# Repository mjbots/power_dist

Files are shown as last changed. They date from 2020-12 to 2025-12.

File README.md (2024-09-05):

# mjbots power_dist and mjpower-ss #

This repository contains hardware and firmware for the mjbots
power_dist and mjpower-ss boards.  Both provide pre-charge,
over-current limiting and connector fanout.  The power_dist
additionally provides energy monitoring and a soft-switch
functionality.

# Specifications #

| Name | power_dist r4.5b | mjpower-ss r2 |
| --- |---|---|
| Voltage Input | 10-44V | 10-54V |
| Current (continous/peak) | 45A/90A | 45/90A |
| Output | 6x XT30 | 6x XT30 |
| Max load capacitance | 4000uF | 4000uF |
| Quiescent current | 300uA | 200uA |
| Dimensions | 80x50mm | 70x50mm |
| Mass | 36g | 34g |
| External switch | X | X |
| Soft switch | X | |
| Onboard switch | | X |
| CAN communication | X | |

# Documentation #

* [Reference](docs/reference.md)

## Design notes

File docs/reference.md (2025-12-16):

mjbots power_dist and mjpower-ss reference

# A. Operation #

The `power_dist` and mjpower-ss boards provides pre-charging, an
external power switch, and a power connector fanout for use in robotic
applications.  Additionally, the `power_dist` provides energy
monitoring and over-current protection, and a soft switch capability.

The input can be directly connected to a battery or power supply.  The
output can be connected to high capacitance loads.

For the `power_dist`, a CAN-FD port allows host software to monitor
the state of the switch, input voltage, power, and energy, and request
that shutdown be delayed to accomplish a "soft power down".  This
documentation refers to the most recent (r4.5b) version of the
`power_dist`.  r4.3 versions are largely compatible with this as well.

# A. Register command set (power_dist only) #

The `power_dist` uses the same register framing and CAN-FD as the mjbots moteus controllers, with alternate definitions for the registers.  [moteus reference](https://github.com/mjbots/moteus/blob/main/docs/reference.md#a-register-command-set)

The default ID for the power_dist is '32', (which notably differs from
the default id of 1 for the moteus controller).

## A.2 ##

The following additional mappings are provided.

### A.2.a Energy (measured in W*hr) ###

- int8 => 1 LSB => 1 W*hr
- int16 => 1 LSB => 0.01 W*hr
- int32 => 1 LSB => 0.000001 W*hr

## Registers ##

### 0x000 - State ###

Mode: Read only

The current operational state of the power_dist.

- 0 => power off
- 1 => precharging
- 2 => power on
- 3 => fault

### 0x001 - Fault Code ###

Mode: Read only

A 7 bit fault code.

### 0x002 - Switch status ###

Mode: Read only

Zero if the switch is current turned off, non-zero otherwise.

### 0x003 - Lock time ###

Mode: Read/write

Power will be maintained for this long after the switch has been
turned off.  The maximum value is 3276.7s, all register scalings
report in units of 100ms (thus int8 will not be able to command or
monitor the full possible scale).

### 0x004 - Boot time ###

Mode: Read

Time since the processor was powered.

### 0x010 - Output Voltage ###

Mode: Read only

The current output voltage

### 0x011 - Output Current ###

Mode: Read only

The current output current.

### 0x012 - Temperature ###

Mode: Read only

The current output FET temperature.

### 0x013 - Energy ###

Mode: Read only

Total energy provided to the downstream port since power was enabled.

# B. diagnostic command set (power_dist only) #

All `tel` and `conf` class commands from [moteus
reference](https://github.com/mjbots/moteus/blob/main/docs/reference.md#b-diagnostic-command-set)
are supported.  In addition, the following diagnostic mode commands
are available.

## `p lock` ##

Request that the lock time be set.

```
p lock <time_in_100ms>
```

## `p force off` ##

Request that the output be turned off.  The device will not enter
sleep, which differs from the behavior when power off is achieved
through the physical switch.  While the "force" mode is activated, the
switch has no effect.

## `p force on` ##

Request that the output be turned on.  This enables "force" mode,
which disables the physical switch.

## `p force disable` ##

Remove "force" mode, which will re-enable the physical switch.

# C. Mechanical / Electrical #

## Mechanical ##

`power_dist`: 4x M2.5 mounting holes are provided in a 74mm x 44mm rectangular pattern.

`mjpower-ss`: 4x M2.5 mounting holes are provided in a 64mm x 44mm rectangular pattern.

## Pinout ##

### XT-90 Input ###

The XT-90 connector has a `-` and a `+` imprint on the housing.

### XT-30 Output ###

The XT-30 connectors have a `-` and a `+` imprint on the housing.

### JST PH-4 Switch ###

A small white dot is present on the silk screen near pin 1.

 - 1 - LED+ - LED positive
 - 2 - LED- - LED ground
 - 3 - SWG - Switch ground
 - 4 - SWP - Switch positive

### Onboard Switch (mjpower-ss only) ###

The onboard switch is connected in parallel to the external switch.
If either the onboard switch is set to the ON position, or the
external switch pins are tied together, the board will pre-charge and
provide power to the output when the input voltage reaches a small
threshold below the minimum input voltage.

### JST PH-3 CAN (power_dist only) ###

Looking at the pins of the connector with the mjbots logo right side
up, the pins are numbered from the bottom to the top.

 - 1 - CAN_H
 - 2 - CAN_L
 - 3 - GND

NOTE 1: CAN connections should be terminated by a 120 ohm resistor at
both ends of a bus.  Some mjbots products have built in termination
resistors, such as the pi3hat.  The fdcanusb has a software
configurable termination resistor that is by default on.  The
power_dist board has no termination resistors.  For very short runs,
the system will work terminated only on one side.  However, when runs
become longer than 0.5m, you will likely need to terminate both ends.
This can be done by crimping a 120 ohm resistor into a JST PH3
connector and connecting it to the open data connector.

NOTE 2: Ground may not be necessary, only one path through ground in a
system should exist to avoid ground loops.  In a typical robot
application with a common ground, that role is filled by the power
ground.  However, in desktop applications, it may be appropriate to
connect the CAN ground if the device power supply is otherwise
isolated.

### JST ZH-6 SWD (power_dist only) ###

Looking at the pins of the connector with the mjbots logo right side
up the pins are numbered 1 to 6 from top to bottom.

 - 1 - NC
 - 2 - NRST
 - 3 - SWDIO
 - 4 - GND
 - 5 - SWCLK
 - 6 - 3.3V

# D. Maintenance (power_dist only) #

## Building firmware ##

Building is supported on Ubuntu 20.04 with the following command:

```
tools/bazel test //:target
```

## Flashing firmware ##

A firmware image (.elf file), can be flashed from a linux PC using the
6-pin SWD debug connector.

One time:

```
sudo apt install binutils-arm-none-eabi
```

Ensure that power is applied, the switch is turned on, and no loads
are connected, then:

```
fw/flash.py optional/path/to/file.elf
```

## openocd ##

As with moteus, openocd 0.11.0 or newer is required, see:

https://github.com/mjbots/moteus/blob/main/docs/reference.md#openocd

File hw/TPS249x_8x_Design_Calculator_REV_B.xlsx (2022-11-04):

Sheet: Instructions
 | © 2016
TPS249x/8x Design Tool- Rev. B
Typical design procedure
Typical applications require multiple passes through the design tool using MOSFET factors such as transient
thermal response and safe operating area curves. Refer to the following application reports for more detail.
Robust Hot Swap Design (http://www.ti.com/lit/pdf/slva673)
The basic design process follows:
1. Enter operating conditions.
2. Select current limit parameters.
3. Enter MOSTFET SOA characteristics & power limit.
4. Select start up conditions (load and/or soft start). Check whether FET is operating with reasonable margin, within the SOA curve.
If not, try changing start-up conditions (soft start values, timer values), add more FETs in parallel, or switch to FET with better SOA.
5. Enter desired UVLO and OVLO values to get recommended resistor values.
6. Done
Notes
1. This worksheet is designed for use with Microsoft Excel 5.0 or later. Its use is intended to assist power supply designers in their
routine, day-to-day calculations.
2. All worksheets have light green inputs cells, white calculated cells, yellow warning cells and red high-risk cells.
3. Formulas and device constants used in the spreadsheet are locked to prohibit them from accidentally being overwritten or deleted.
TEXAS INSTRUMENTS TEXT FILE LICENSE Copyright (c) 2014 Texas Instruments Incorporated All rights reserved not granted herein. Limited License. Texas Instruments Incorporated grants a world-wide, royalty-free, non-exclusive license under copyrights and patents it now or hereafter owns or controls to make, have made, use, import, offer to sell and sell ("Utilize") this software subject to the terms herein. With respect to the foregoing patent license, such license is granted solely to the extent that any such patent is necessary to Utilize the software alone. The patent license shall not apply to any combinations which include this software, other than combinations with devices manufactured by or for TI (“TI Devices”). No hardware patent is licensed hereunder. Redistributions must preserve existing copyright notices and reproduce this license (including the above copyright notice and the disclaimer and (if applicable) source code license limitations below) in the documentation and/or other materials provided with the distribution Redistribution and use in binary form, without modification, are permitted provided that the following conditions are met: * No reverse engineering, decompilation, or disassembly of this software is permitted with respect to any software provided in binary form. * any redistribution and use are licensed by TI for use only with TI Devices. * Nothing shall obligate TI to provide you with source code for the software licensed and provided to you in obje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

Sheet: Design Calculator
TPS2490/1/2/3 & TPS2480/1/2/3 Hot Swap Design Tool
 | www.ti.com/hotswap
 |  |  |  |  |  |  |  |  |  |  |  |  | Yes
 |  |  | Enter Values in Green Shaded Cells |  |  |  |  |  |  |  |  |  | No
 |  |  | Calculated Values are shown in White Cells
 |  |  | Yellow and Red cells highlight pottential issues with the design. Red highlights items that are higher risk.
 | Step 0: Calculator Tutorials |  | Note: Before proceeding, please watch the video tutorials listed to ensure accurate results from this tool!
 |  |  | Steps 1 & 2: Operating Conditions, Current Limit, & Circuit Breaker (7:41) (https://training.ti.com/node/1133677)
 |  |  | Step 3: MOSFET Selection (9:58) (https://training.ti.com/node/1133673)
 |  |  | Step 4: Startup (10:32) (https://training.ti.com/node/1133664)
 |  |  | Step 5: UVLO, OVLO & PGD Thresholds (4:20) (https://training.ti.com/node/1133681)
 |  |  | TPS2490 Datasheet (http://www.ti.com/product/TPS2490)
 |  |  | I understand and agree to watch the video tutorials if help is needed. (Choose Yes to enable the calculator.) |  |  | Yes
 |  |  | Assure to follow the layout and application guidelines listed on the datasheet. |  |  | Yes
 |  |  | *For additional questions not addressed in the videos, please post on E2E.ti.com
 | Step 1: Operating Conditions |  |  | Minimum Input Operating Voltage: VIN(MIN) | 12 | V
 |  |  |  | Nominal Input Operating Voltage: VIN(NOM) | 48 | V
 |  |  |  | Maximum Input Operating Voltage: VIN(MAX) | 52 | V
 |  |  |  | Maximum Load Current: IOUT(MAX) | 45 | A
 |  |  |  | Maximum Output Load Capacitance: CLOAD | 4000 | µF
 |  |  |  | Maximum Ambient Operating Temperature: TMAX | 55 | oC
 | Steps 1 & 2: Operating Conditions, Current Limit, & Circuit Breaker (https://training.ti.com/node/1133677)
 | Step 2: Current Limit and Circuit Breaker |  |  | Maximum Recommended Value for Rs | 0.99 | mW |  |  |  |  | 46 mV
 |  |  |  | Use External Resistor Divider to Reduce Effecitve RS | No |  |  |  |  |  | Yes
 |  |  |  | Enter the Resistance for RS | 0.5 | mW |  |  |  |  | No
 |  |  |  | Recommended Value for RCL1 | NA | W
 |  |  |  | Recommended Value for RCL2 | NA | W
 |  |  |  | Enter value for RCL1 | 10 | W |  |  |  |  | 1
 |  |  |  | Enter value for RCL2 | 2 | W
 | Steps 1 & 2: Operating Conditions, Current Limit, & Circuit Breaker (https://training.ti.com/node/1133677) |  |  | Effective Sense Resistance (RS,EFF) | 0.50 | mW
 |  |  |  | Resulting Minimum Current Limit | 90.0 | A
 |  |  |  | Resulting Typical Current Limit | 100.0 | A
 |  |  |  | Resulting Maximum Current Limit | 110.0 | A |  |  |  |  | Retry
 |  |  |  | Maximum Power Dissipation in RS | 6.0 | W |  |  |  |  | Latch Off
 | Step 3: MOSFET Selection |  |  | Q1 FET Name | PSMN3R7-100BSE
 |  |  |  | Estimated MOSFET RQJA | 30 | oC/W |  |  |  |  | 2.975206612 | 4
 |  |  |  | Number of MosFETs | 3 | # |  |  |  |  | Values Used
 |  |  |  | MOSFET On resistance @ TJ,DC | 3.95 | mW |  |  |  |  | 3.95
 |  |  |  | Maximum FET Junction Temperature | 175 | oC |  |  |  |  | 175
 |  |  |  | 100ms SOA Current (re-use 1ms data if unavailable) @ VIN(MAX) | 120.0 | A |  |  |  |  | 120
 |  |  |  | 1ms SOA Current @ VIN(MAX) | 30.0 | A |  |  |  |  | 30
 | Step 3: MOSFET Selection (https://training.ti.com/node/1133673) |  |  | 10ms SOA Current @ VIN(MAX) | 12.0 | A |  |  |  |  | 12
 |  |  |  | 100ms Current at @ VIN(MAX) (use DC if 100ms not available) | 5.0 | A |  |  |  |  | 5
 |  |  |  | 1s or DC SOA Current at @ VIN(MAX) (use DC if 1s not available) | 2.0 | A |  |  |  |  | 2
 |  |  |  | FET Power dissapation at full load (per FET) | 0.9 | W
 | Note: TI recommends choosing a FET with SOA current specified for 100ms and/or 1s or DC. If choosing a FET without these parameters, this calculator will estimate the values via extrapolation, which leaves an inherent associated risk. |  |  | Maximum steady state FET Junction Temperature (TJ,DC) | 81.7 | oC
 |  |  |  | Minimum Power Limit to Ensure Vsns > 5mV & Vprog > 0.4V (PLIM,MIN) | 520.0 | W
 |  |  |  | Target Power Limit | 500.0 | W
 |  |  |  | Select R3 | 45.0 | kW
 |  |  |  | Calculated R4 | 6.43 | kW
 |  |  |  | Actual R4 (Select next available std. value) | 6.8 | kW | Note: Hover here to see the 3 values affecting this curve, consult a thermal expert if you are unsure!
 |  |  |  | Actual PLIM | 525.10 | W
 | Step 4: Startup |  |  | Load Turn-On Threshold | 0 | V
 |  |  |  | Startup Load Type | Constant Current
 |  |  |  | Startup Load Value | 0.3 | A |  |  |  |  | Constant Current
 |  |  |  | Use External Soft-Start Control | Yes |  |  |  |  |  | Resistive
 |  |  |  | Typical Start Time with Vinmax (Tstart) | 63.82 | ms
 |  |  |  | IFET - ILOAD margin (lowest for Vout range) | 91.57127992%
 |  |  |  | Target Fault Timer: Tstart + Margin | 111.68 | ms
 |  |  |  | Target Timer capacitance | 698.01 | nF
 |  |  |  | Selected Timer capacitance | 220 | nF
 | Step 4: Startup (https://training.ti.com/node/1133664) |  |  | Final Fault Timer(Tfault) | 35.20 | ms
 |  |  |  | Derated SOA / PLIM | 1.53
 |  |  |  | Can a "hot" board be hotplugged | No
 |  |  |  | Recommended slew Rate (max) | 0.89 | V/ms
 |  |  |  | Recommended slew Rate (min) | 0.09 | V/ms
 | Note: This is the typical dv/dt rate, but max value can be larger. This is because the gate source current can vary from 16uA to 28uA. Thus TI recommends keeping the overall SOA margin during start-up >1.5 in order to compensate for this. |  |  | dv/dt rate on Vout | 0.25 | V/ms
 |  |  |  | calculated SS capacitance | 88.00 | nF
 |  |  |  | actual SS capacitance | 27 | nF
 |  |  |  | actual dv/dt rate on Vout | 0.81 | V/ms
 |  |  |  | SOA margin during start-up | 1.74
 |  |  |  | Target Fault Time | 0.4 | ms
 |  |  |  | Calculated Timer Capacitance | 2.50 | nF
 |  |  |  | Actual Timer Capacitance (pick one smaller than CT,CALC) | 10 | nF
 |  |  |  | Actual Fault Time (Tfault) | 1.60 | ms
 |  |  |  | SOA margin during "hot-short" or "start-into short" | 1.53
 | Step 5: UVLO, OVLO & PGD Thresholds |  |  | Target Under - Voltage | 30 | V |  |  |  |  | Option B
 |  |  |  | Recommended R2 | 10.00 | kW
 |  |  |  | Actual R2 | 10 | kW
 |  |  |  | Calculated R1 | 212.22 | kW
 |  |  |  | Actual R1 | 212 | kW
 |  | Resulting Thresholds: | Minimum | Typical | Maximum
 | Step 5: UVLO, OVLO & PGD Thresholds (https://training.ti.com/node/1133681) | Resulting Upper UVLO Threshold = | 29.30 | 29.97 | 30.64 | V
 |  | Resulting Lower UVLO Threshold = | 27.08 | 27.75 | 28.42 | V
 | Design Summary |  |  | RS = | 0.5 | mW
 |  |  |  | RCL1 = | DNP | W
 |  |  |  | RCL2 = | short | W
 |  |  |  | R1 = | 212 | kW |  |  | Typical | Units
 |  |  |  | R2 = | 10 | kW |  | Current limit | 100.0 | A
 |  |  |  | R3 = | 45.0 | kW |  | Power Limit | 525.0965251 | W
 |  |  |  | R4 = | 6.8 | kW |  | Fault Timeout | 1.600 | ms
 |  |  |  | CT = | 10.00 | nF |  | Upper UVLO Threshold | 30.0 | V
 |  |  |  | C1 = | 0.10 | µF |  | Lower UVLO Threshold | 27.8 | V
 |  |  |  | Q1 = | PSMN3R7-100BSE
 |  |  |  | RG = | 1 | kW
 |  |  |  | CG = | 27 | nF
 | Notes: | 1. Although not mandatory, CIN provides transient suppression at the VIN pin
 |  | 2. A TVS clamp from VIN to GND is absolutely mandatory to clamp the voltage overshoot upon MOSFET turn-off, e.g. during circuit breaker
 |  | 3. Componet tolerances not accounted for in Min/Max Calculations.
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

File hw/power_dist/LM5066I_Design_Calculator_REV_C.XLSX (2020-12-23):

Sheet: Instructions_Disclaimer
 | © 2014
LM5066I Design Tool- Rev. C
Typical design procedure
Typical applications require multiple passes through the design tool using MOSFET factors such as transient
thermal response and safe operating area curves. Refer to the following application reports for more detail.
Robust Hot Swap Design (http://www.ti.com/lit/ds/snvs452d/snvs452d.pdf)
LM5066I Datasheet (See "Applications and Implementation") (http://www.ti.com/lit/gpn/lm5066i)
The basic design process follows:
1. Enter operating conditions.
2. Select current limit parameters.
3. Enter MOSTFET SOA characteristics & power limit.
4. Select start up conditions (load and/or soft start). Check whether FET is operating with reasonable margin, within the SOA curve.
If not, try changing start-up conditions (soft start values, timer values), add more FETs in parallel, or switch to FET with better SOA.
5. Enter desired UVLO and OVLO values to get recommended resistor values.
6. Done
Notes
1. This worksheet is designed for use with Microsoft Excel 5.0 or later. Its use is intended to assist power supply designers in their
routine, day-to-day calculations.
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

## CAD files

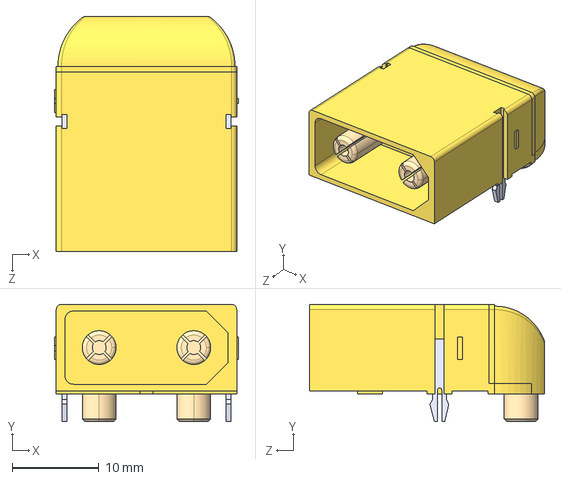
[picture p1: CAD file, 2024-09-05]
hw/mjpower-ss/3d/XT90PW-M.step
21.2 x 13.5 x 27.1 mm

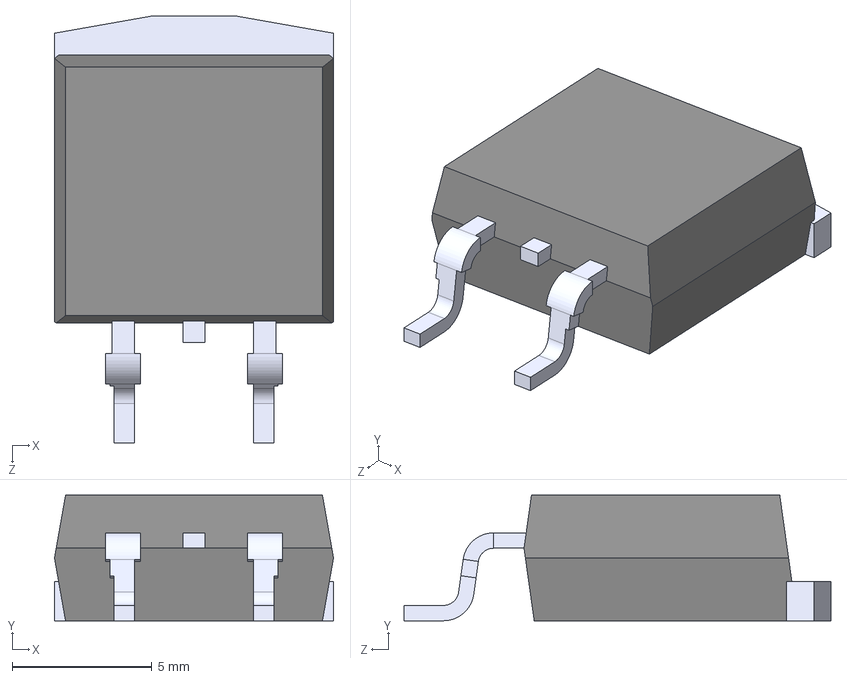
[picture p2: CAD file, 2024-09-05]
hw/mjpower-ss/3d/PSMN3R7-100BSEJ.step
10.0 x 4.50 x 15.3 mm

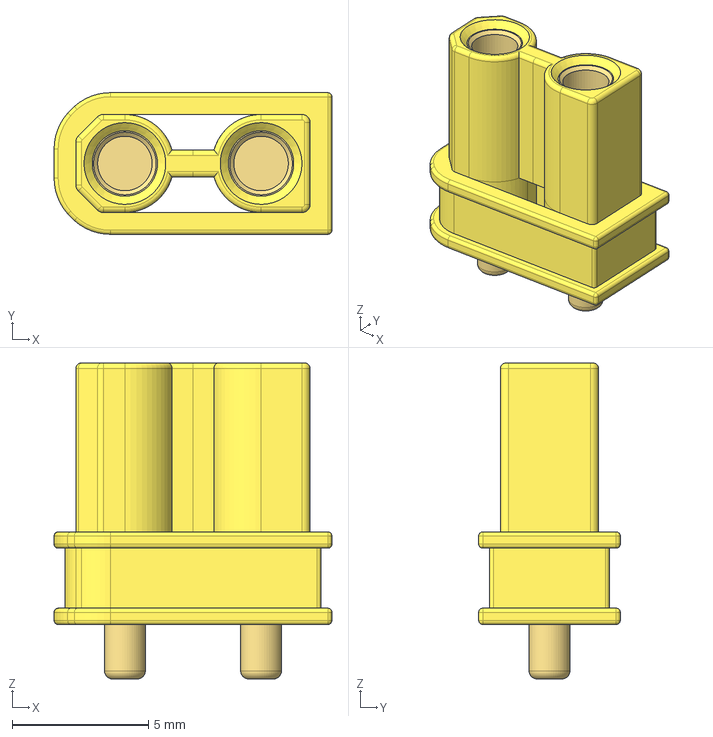
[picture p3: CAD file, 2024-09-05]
hw/mjpower-ss/3d/Amass_XT30UPB-F.step
10.2 x 5.20 x 11.6 mm

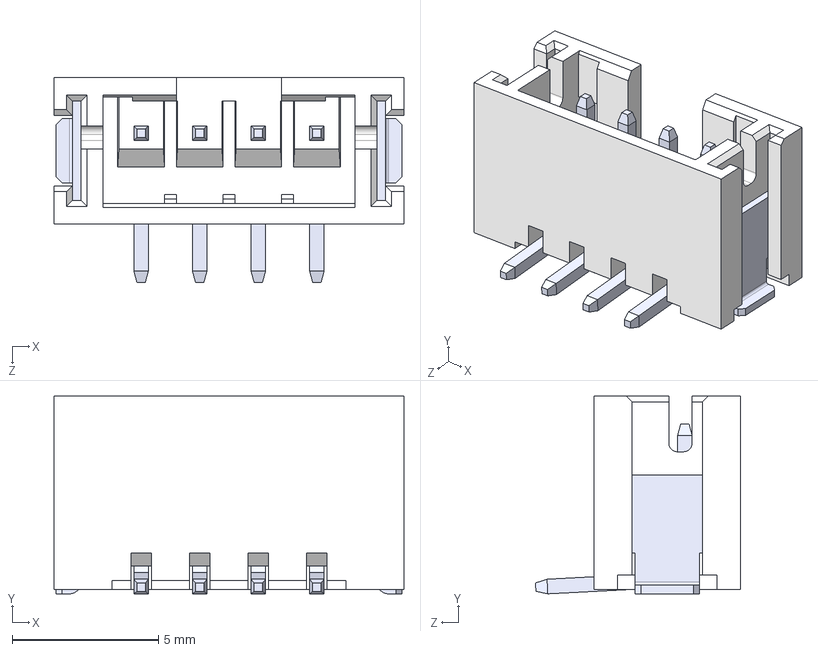
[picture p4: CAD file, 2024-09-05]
hw/mjpower-ss/3d/B4B-PH-SM4-TB.step
12.0 x 6.75 x 7.00 mm

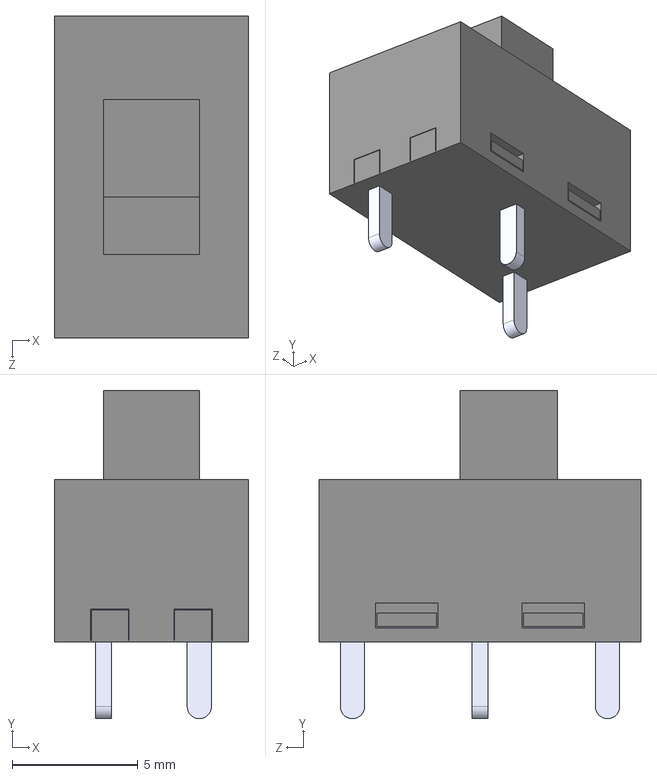
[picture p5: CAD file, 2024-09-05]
hw/mjpower-ss/3d/G-107-0513.step
7.75 x 13.1 x 12.8 mm

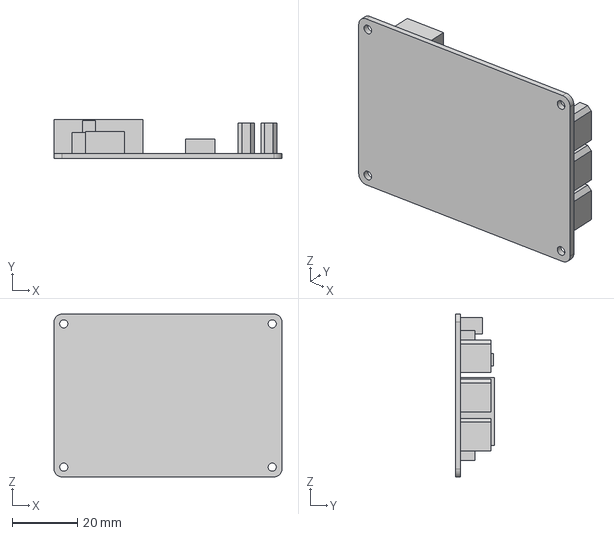
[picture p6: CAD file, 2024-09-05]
hw/mjpower-ss/r2/20240827-mjpower-ss-r2.step
70.0 x 12.1 x 50.0 mm

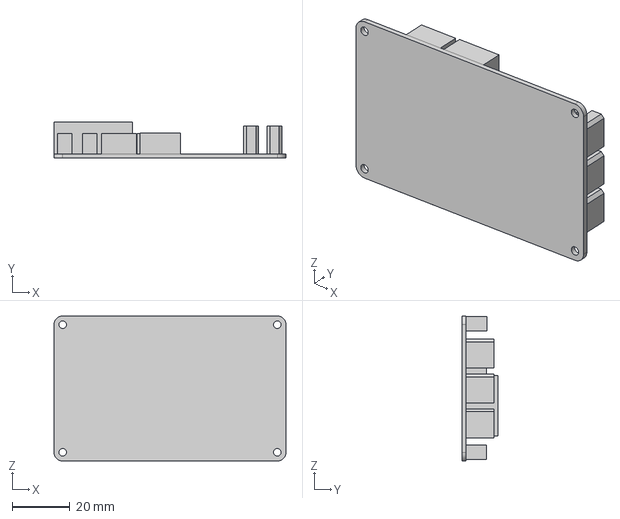
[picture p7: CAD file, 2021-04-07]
hw/power_dist/r4.3b/20210407-power_dist-r43b-mechanical.step
80.0 x 12.5 x 50.0 mm

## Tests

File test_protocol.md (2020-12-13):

# power_dist test protocol #

Power on with maximal capacitance and constant power load
 * Ensure proper dv/dt rise time

Proper quiescent current in shutdown

Verify current, voltage, and power measurements as reported over CAN

Max continuous current

Max peak current

Startup in short

Short while running

Turn off at max continuous load

Verify current sense and energy tracking with regen

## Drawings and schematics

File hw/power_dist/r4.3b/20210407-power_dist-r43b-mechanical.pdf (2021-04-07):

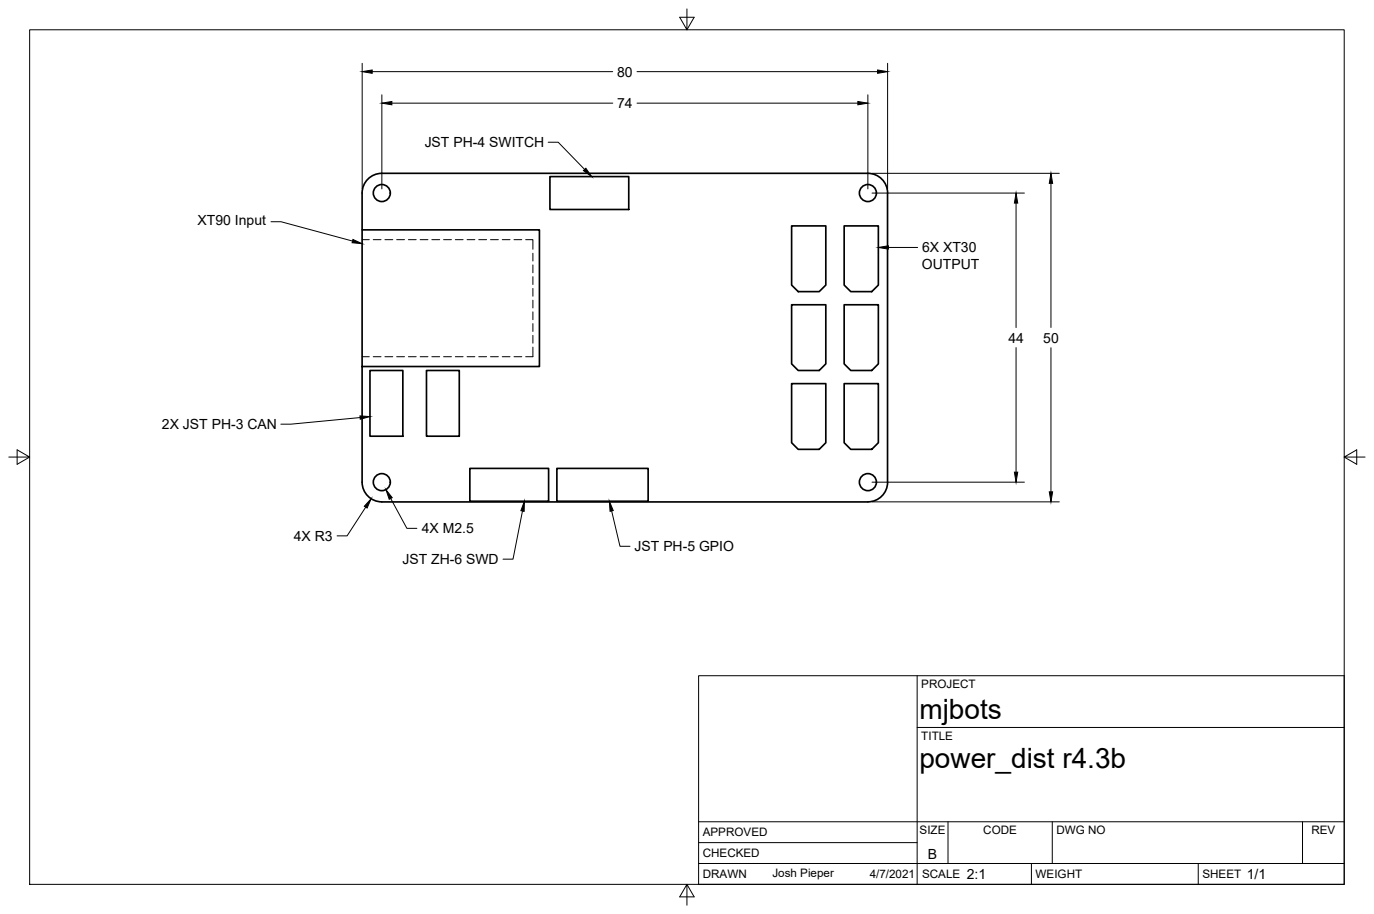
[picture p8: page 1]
SIZE; CODE; DWG NO; REV; Josh Pieper; power_dist r4.3b; XT90 Input

JST PH-4 SWITCH

2X JST PH-3 CAN

JST PH-5 GPIO

JST ZH-6 SWD

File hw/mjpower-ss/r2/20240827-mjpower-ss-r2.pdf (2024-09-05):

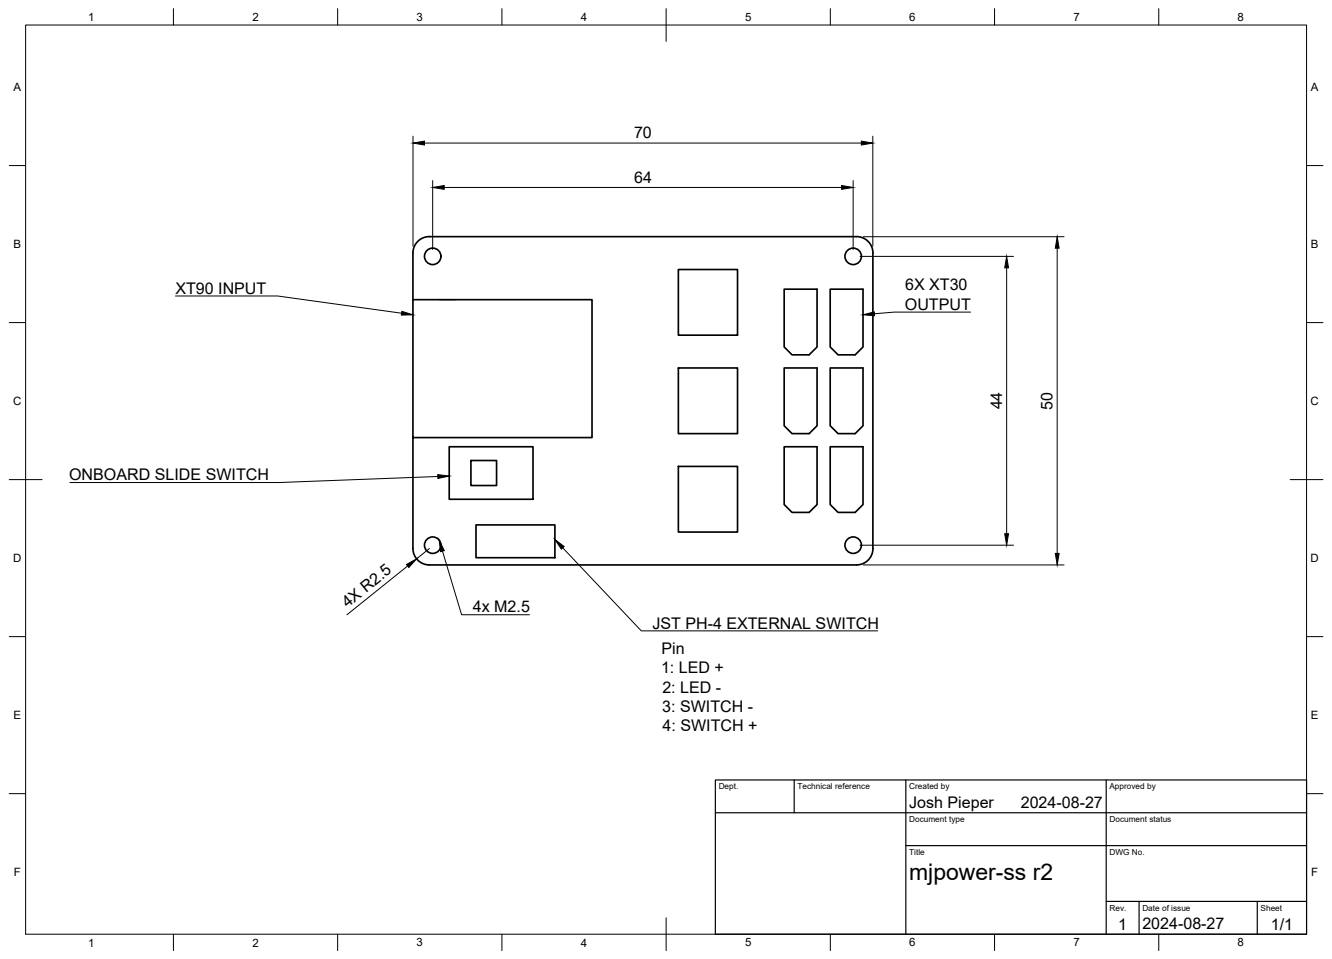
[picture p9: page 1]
Title; DWG No.; Rev.; Date of issue; Sheet; mjpower-ss r2; XT90 INPUT

ONBOARD SLIDE SWITCH

JST PH-4 EXTERNAL SWITCH
Pin
1: LED +
2: LED -
3: SWITCH -
4: SWITCH +

Dept. | Technical reference | Created by Josh Pieper 2024-08-27 | Approved by

Document type | Document status

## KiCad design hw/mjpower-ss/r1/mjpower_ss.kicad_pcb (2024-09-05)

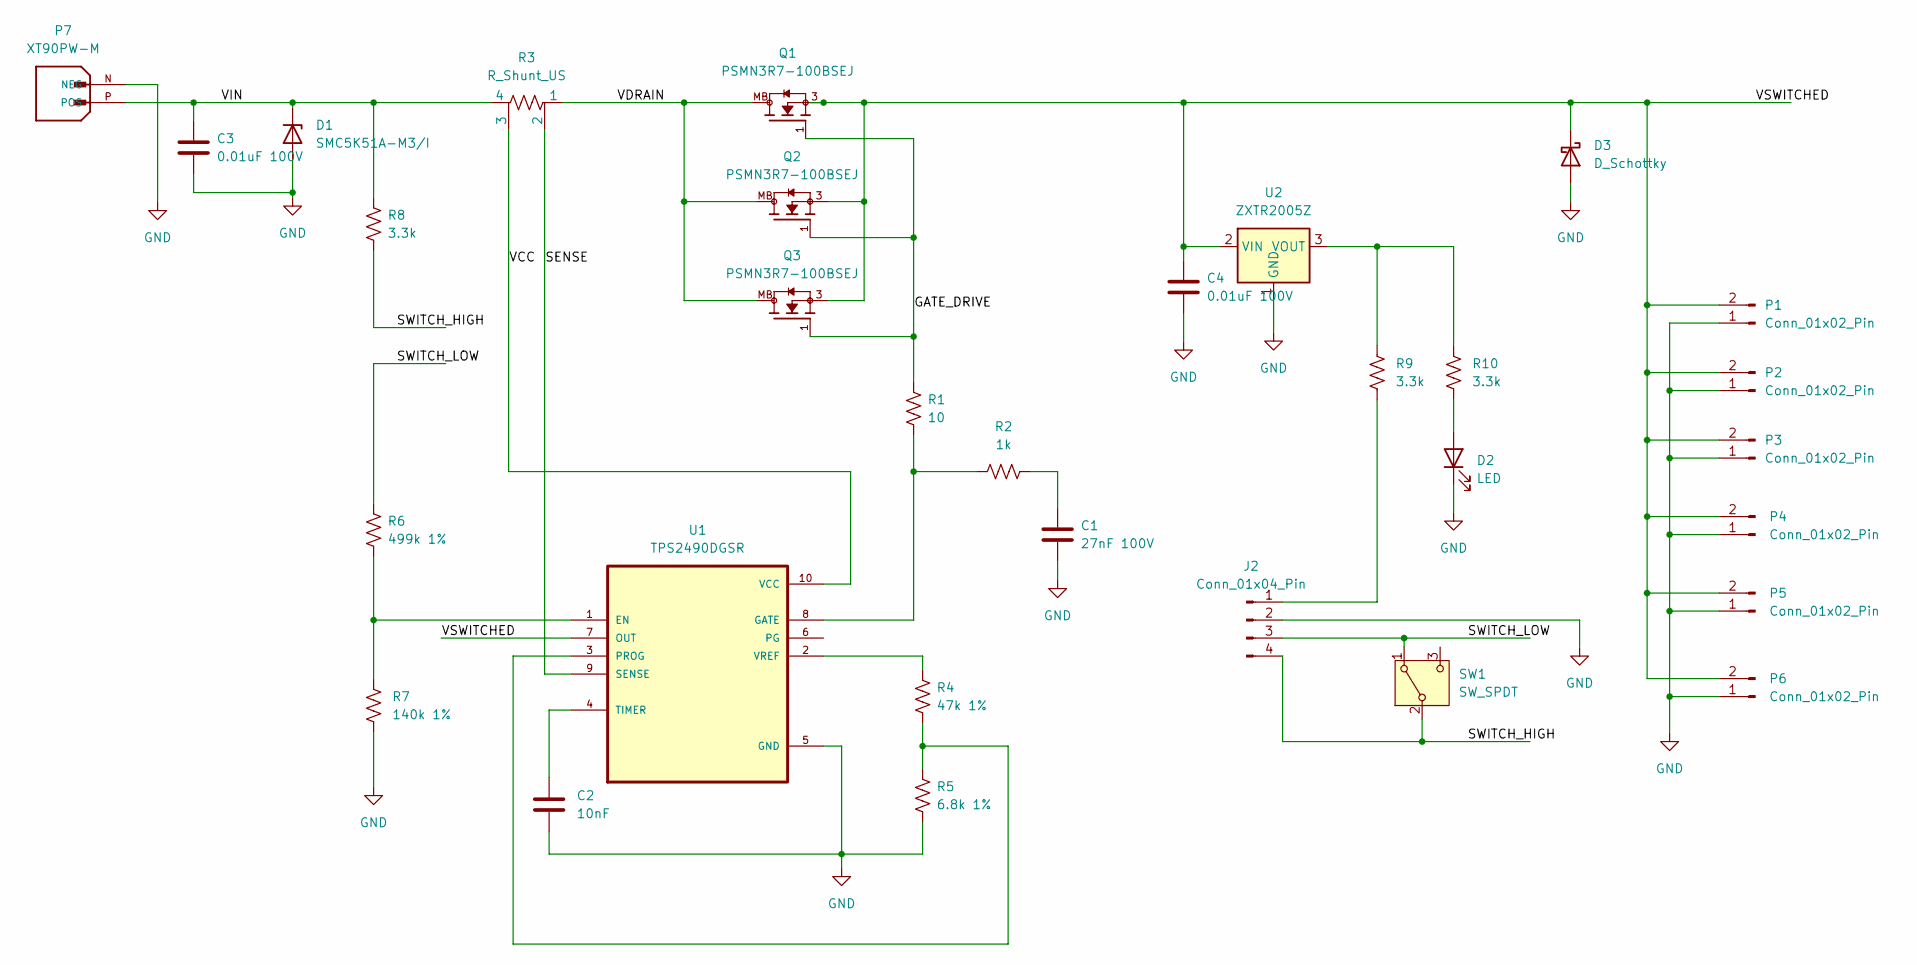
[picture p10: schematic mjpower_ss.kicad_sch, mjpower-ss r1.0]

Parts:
C1: 27nF 100V; C_0603_1608Metric; MPN C0603C273K1RACTU
C2: 10nF; C_0603_1608Metric; MPN MF-CAP-0603-0.01uF
C3, C4: 0.01uF 100V; C_0603_1608Metric; MPN GCM188R72A103KA37D
D1: SMC5K51A-M3/I; D_SMC; MPN SMC5K51A-M3/I
D2: LED; LED_1210_3225Metric; MPN APD3224ZGC-F01
D3: D_Schottky; TO-277A; MPN V10P15-M3/H
J2: Conn_01x04_Pin; JST_B4B-PH-SM4-TB; MPN B4B-PH-SM4-TB(LF)(SN)
P1, P2, P3, P4, P5, P6: Conn_01x02_Pin; XT30UPB-F; MPN XT30UPB-F
P7: XT90PW-M; AMASS_XT90PW-M; MPN XT90PW-M
Q1, Q2, Q3: PSMN3R7-100BSEJ; TRANS_PSMN3R7-100BSEJ; MPN PSMN3R7-100BSEJ
R1: 10; R_0603_1608Metric; MPN MF-RES-0603-10
R2: 1k; R_0603_1608Metric; MPN MF-RES-0603-1K
R3: R_Shunt_US; WSL2512_SHUNT; MPN WSLF2512L5000FEA
R4: 47k 1%; R_0603_1608Metric; MPN RC0603FR-0747KL
R5: 6.8k 1%; R_0603_1608Metric; MPN RC0603FR-076K8L
R6: 499k 1%; R_0603_1608Metric; MPN RC0603FR-07499KL
R7: 140k 1%; R_0603_1608Metric; MPN RC0603FR-07140KL
R8, R9, R10: 3.3k; R_0603_1608Metric; MPN RC0603FR-073K3L
SW1: SW_SPDT; SW_G-107-0513; MPN G-107-0513
U1: TPS2490DGSR; SOP50P490X110-10N; MPN TPS2490DGSR
U2: ZXTR2005Z; SOT-89-3; MPN ZXTR2005Z-13

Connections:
/GATE_DRIVE: Q1.1, Q2.1, Q3.1, R1.1
/SENSE: R3.2, U1.9 (SENSE)
/SWITCH_HIGH: J2.4, R8.2, SW1.2 (B)
/SWITCH_LOW: J2.3, R6.1, SW1.1 (A)
/VCC: R3.3, U1.10 (VCC)
/VDRAIN: Q1.MB, Q2.MB, Q3.MB, R3.1
/VIN: C3.1, D1.1 (K), P7.P (POS), R3.4, R8.1
/VSWITCHED: C4.1, D3.1 (K), P1.2, P2.2, P3.2, P4.2, P5.2, P6.2, Q1.3, Q2.3, Q3.3, U1.7 (OUT), U2.2 (VIN)
GND: C1.2, C2.2, C3.2, C4.2, D1.2 (A), D2.1 (K), D3.2 (A), J2.2, P1.1, P2.1, P3.1, P4.1, P5.1, P6.1, P7.N (NEG), R5.2, R7.2, U1.5 (GND), U2.1 (GND)
unnamed: C1.1, R2.2
unnamed: D2.2 (A), R10.1
unnamed: J2.1, R9.1
unnamed: R6.2, R7.1, U1.1 (EN)
unnamed: R1.2, R2.1, U1.8 (GATE)
unnamed: R4.2, R5.1, U1.3 (PROG)
unnamed: C2.1, U1.4 (TIMER)
unnamed: R4.1, U1.2 (VREF)
unnamed: R9.2, R10.2, U2.3 (VOUT)

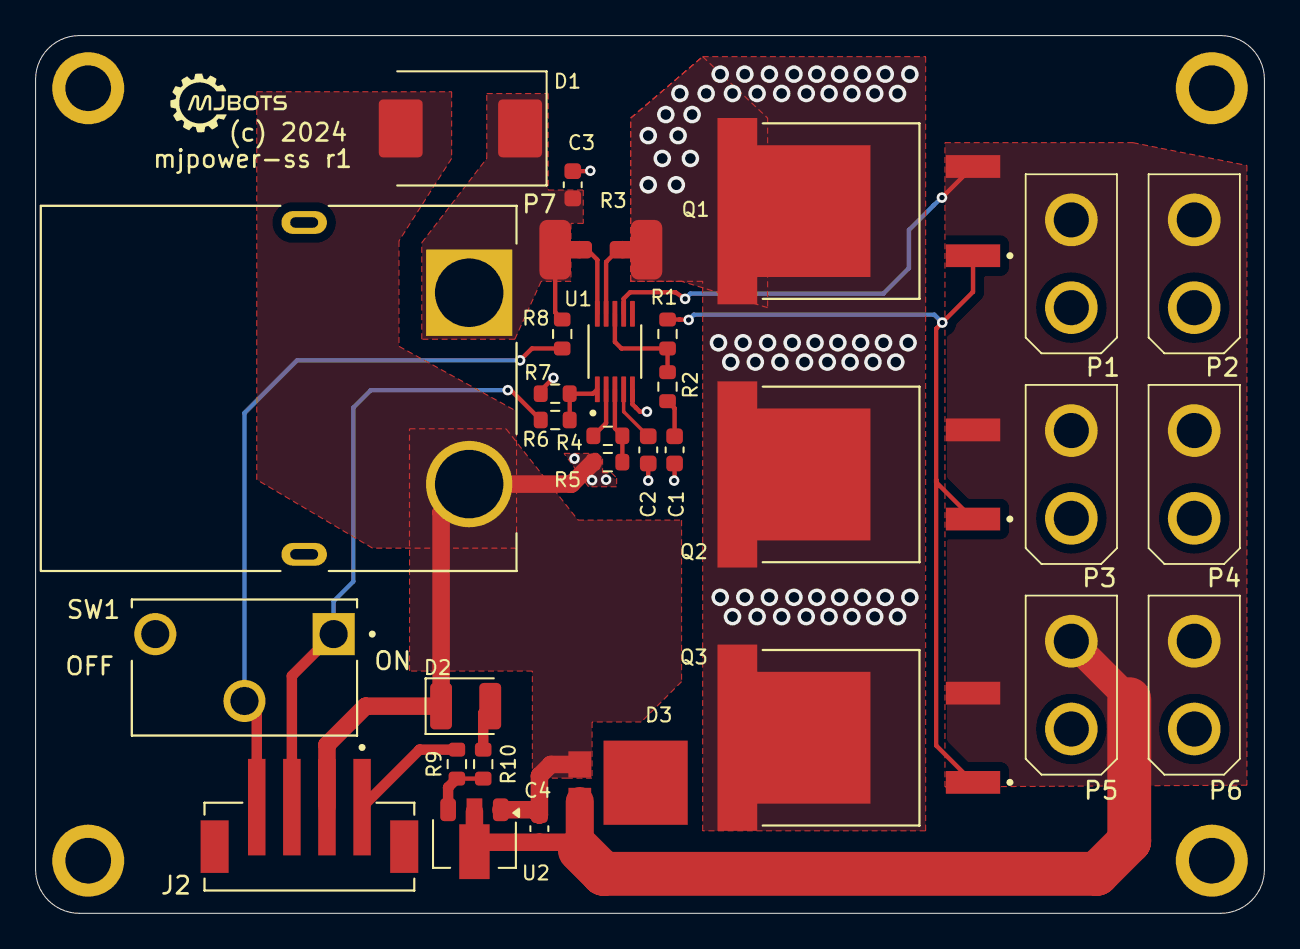
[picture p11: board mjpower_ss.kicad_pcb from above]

Board: 4 copper layers, 70.0 x 50.0 mm, 31 parts (0 on the bottom side), 18 nets.

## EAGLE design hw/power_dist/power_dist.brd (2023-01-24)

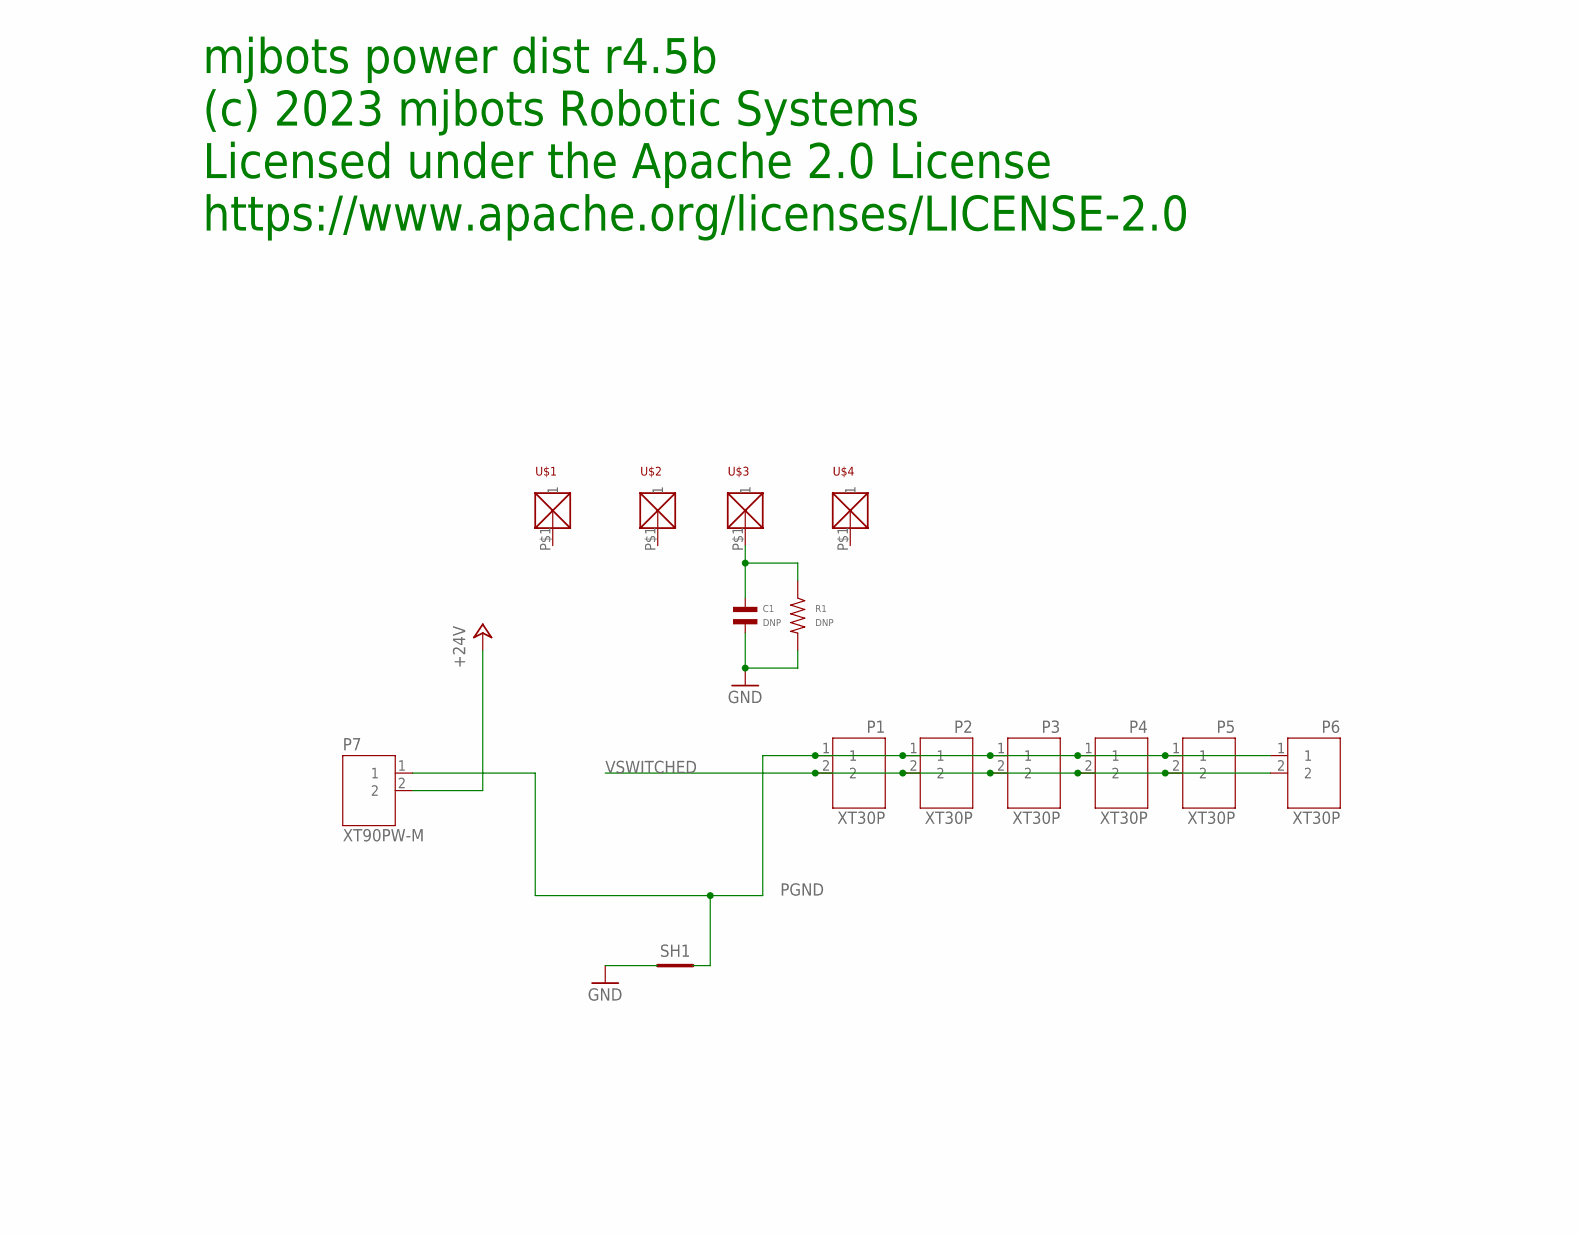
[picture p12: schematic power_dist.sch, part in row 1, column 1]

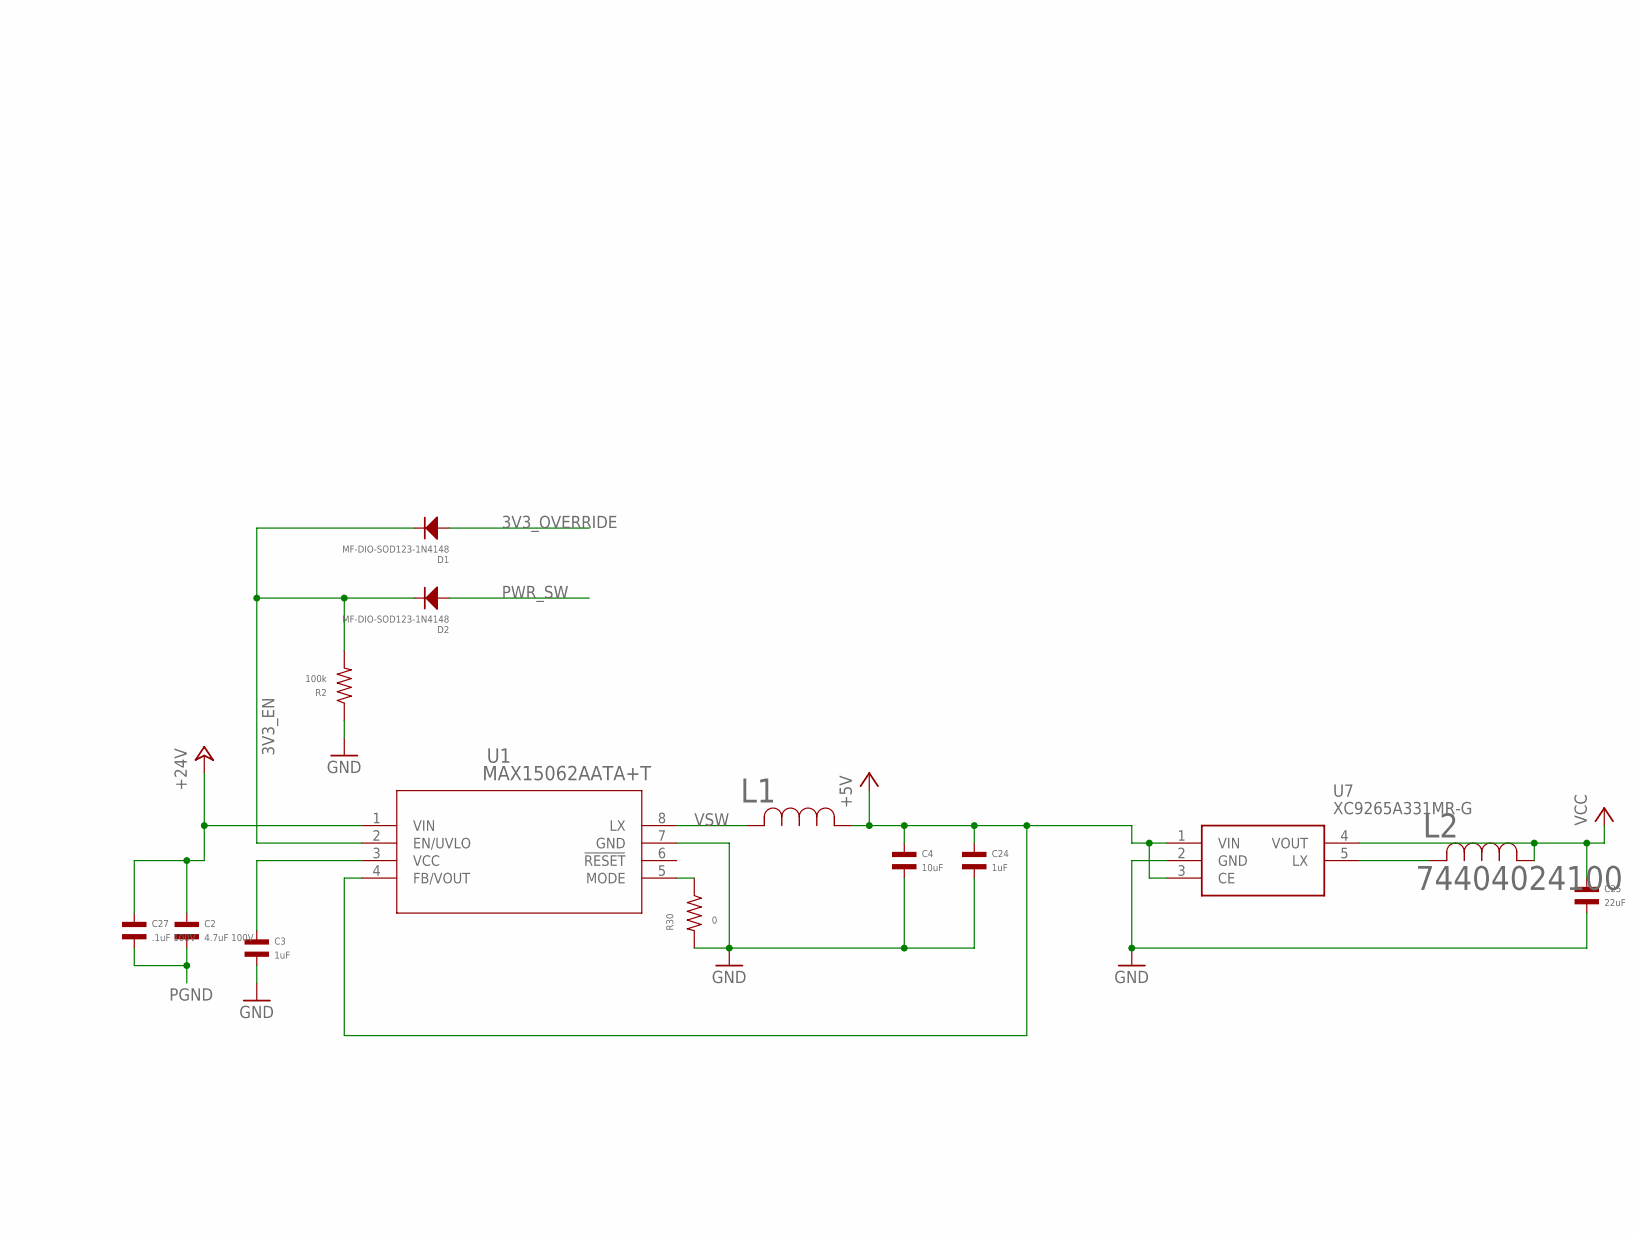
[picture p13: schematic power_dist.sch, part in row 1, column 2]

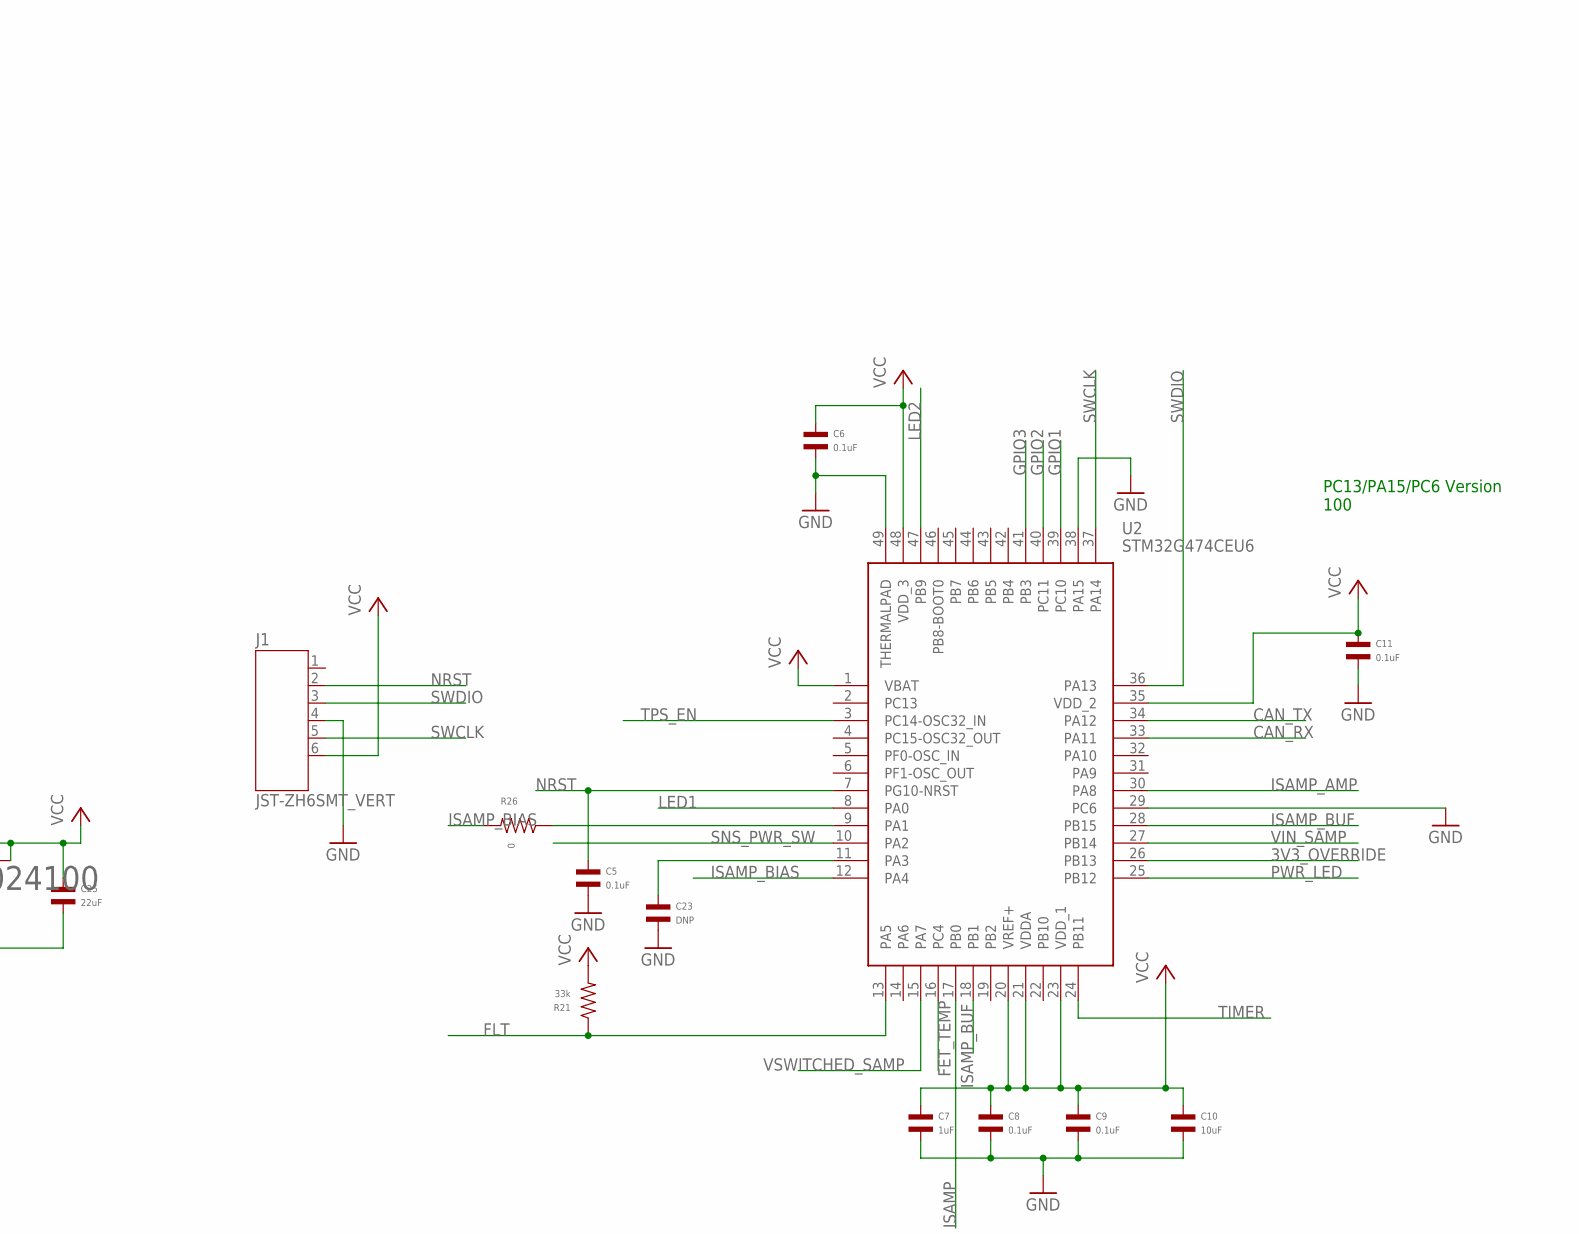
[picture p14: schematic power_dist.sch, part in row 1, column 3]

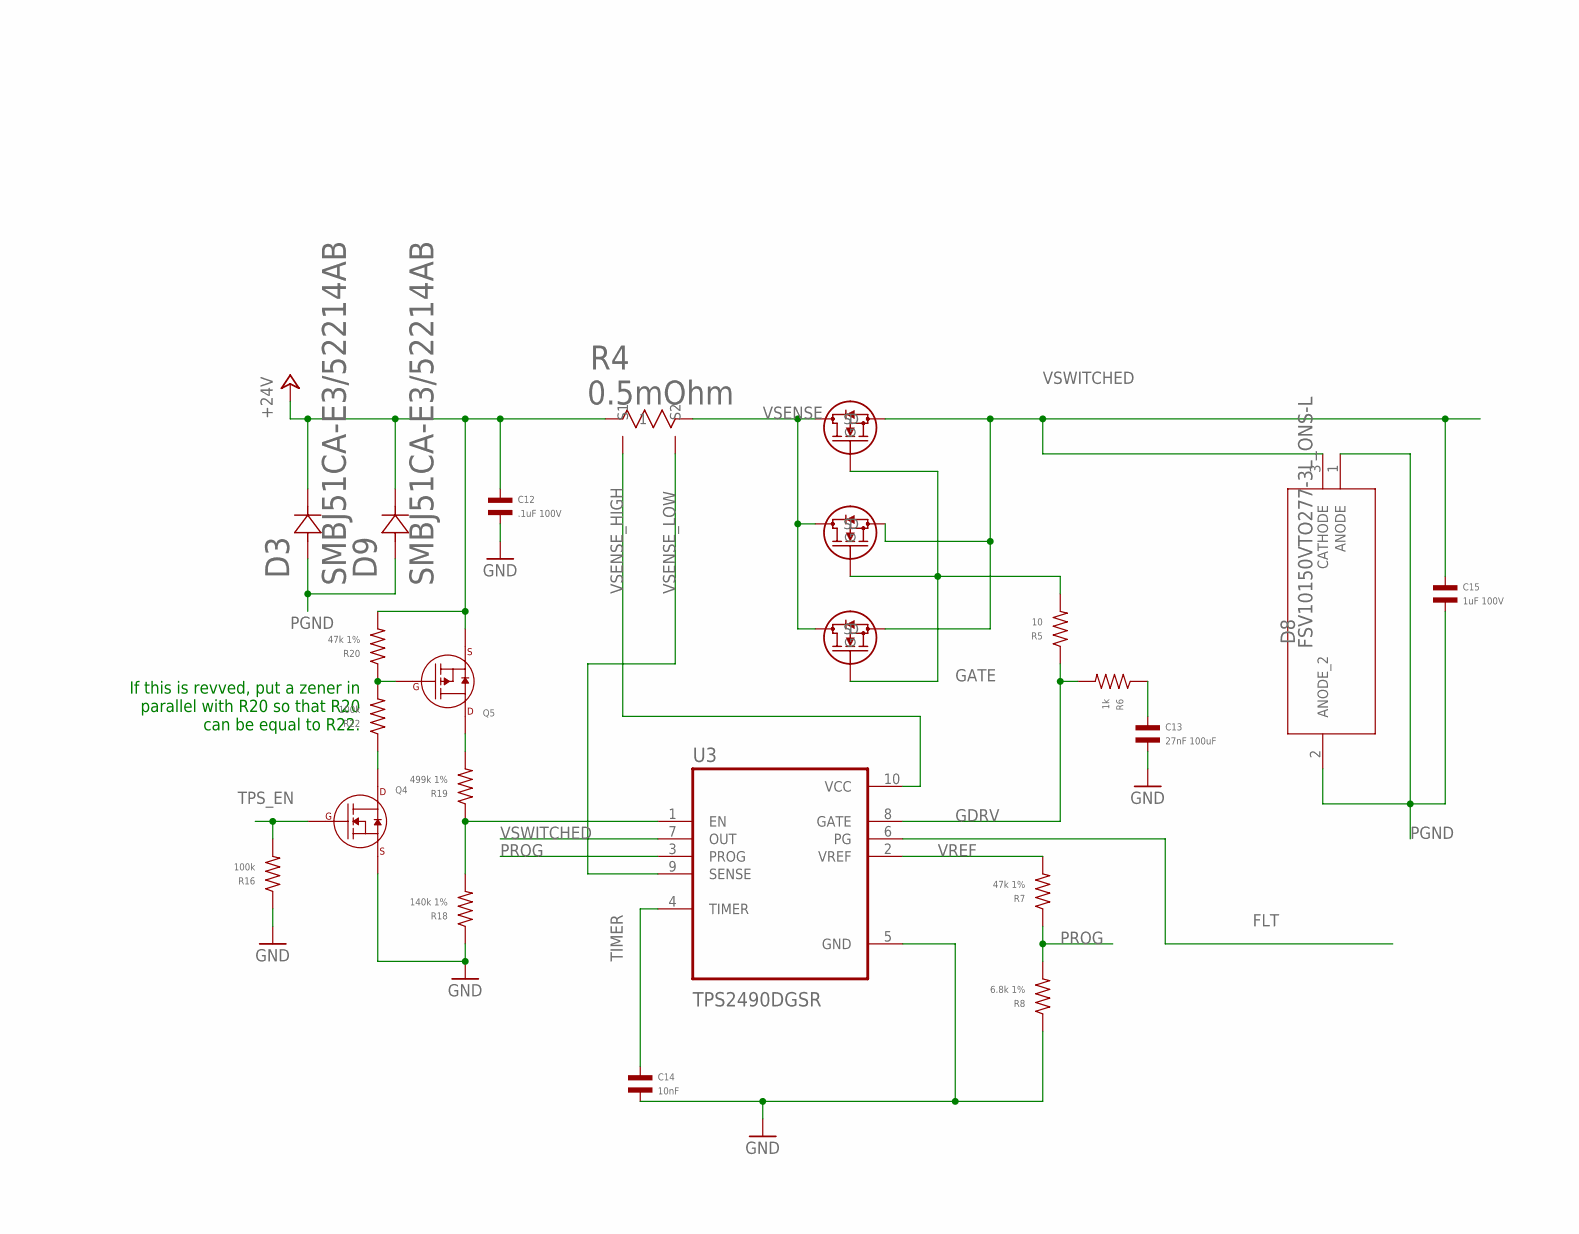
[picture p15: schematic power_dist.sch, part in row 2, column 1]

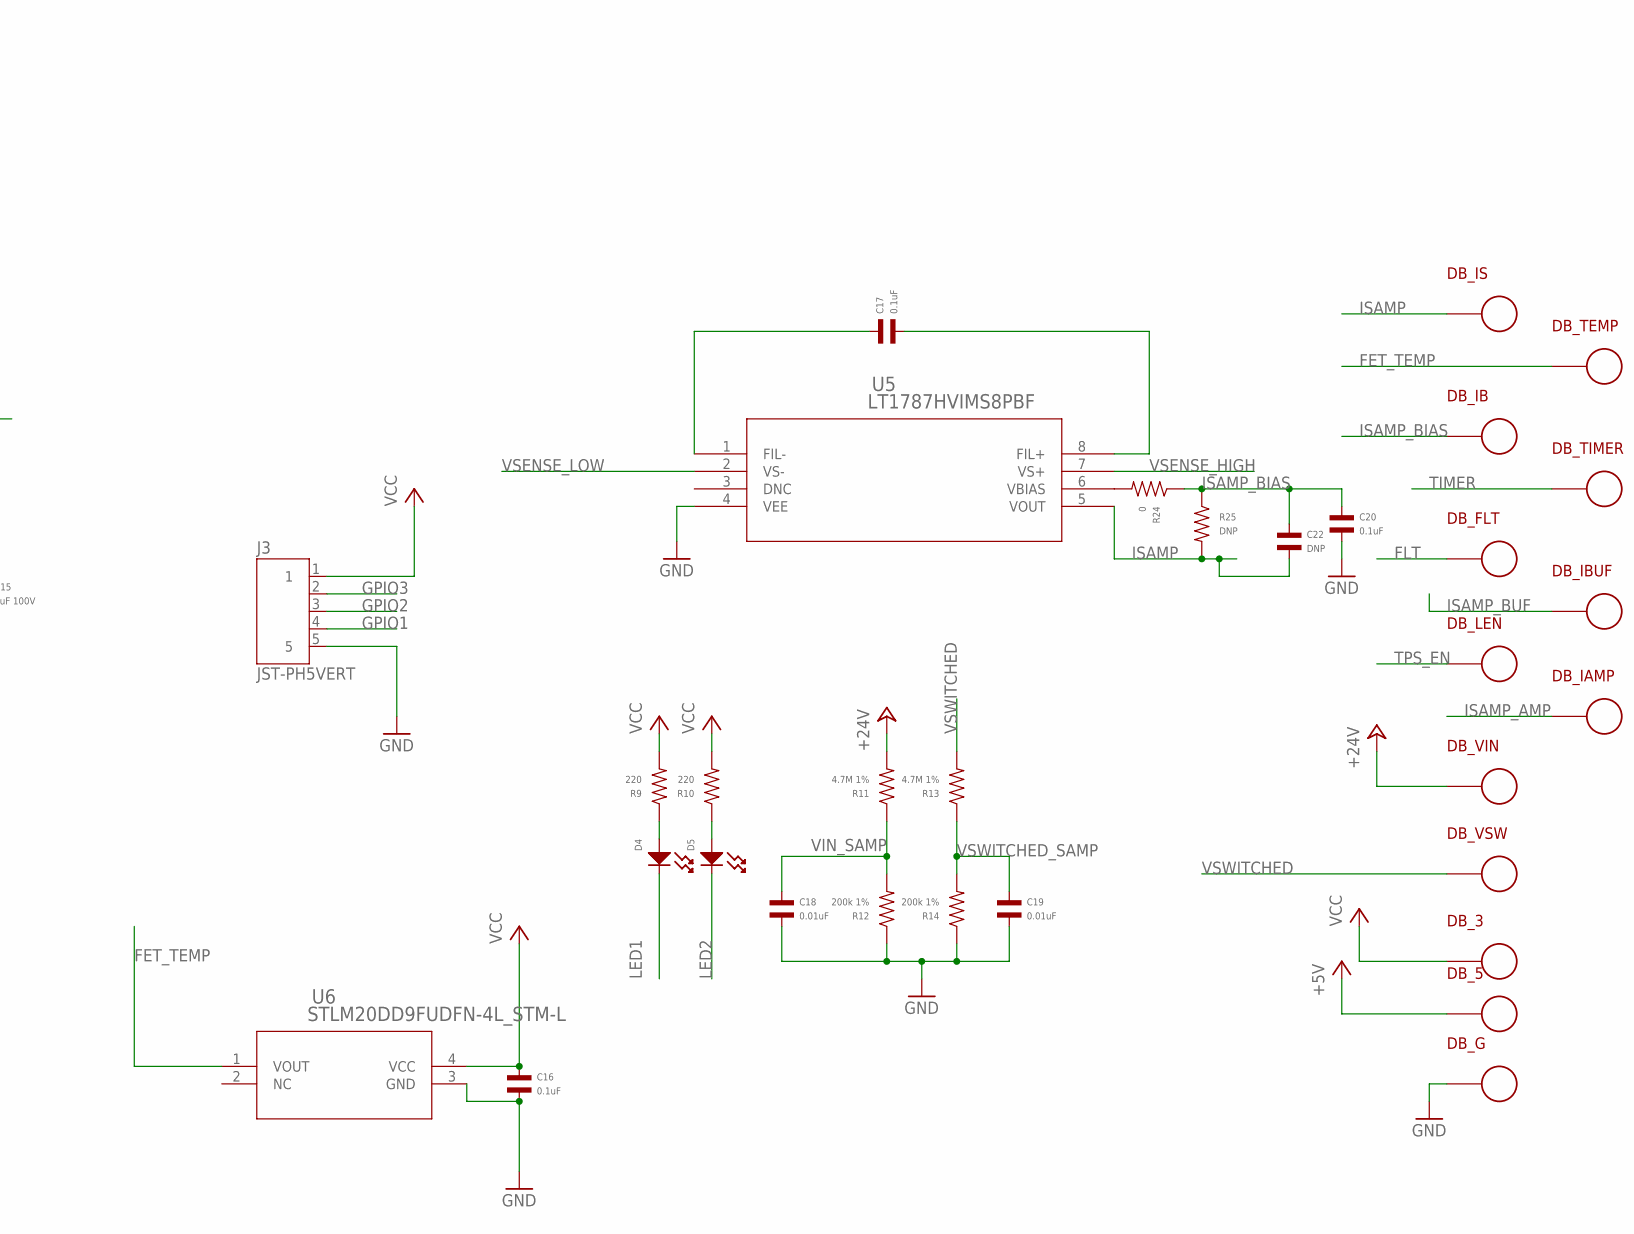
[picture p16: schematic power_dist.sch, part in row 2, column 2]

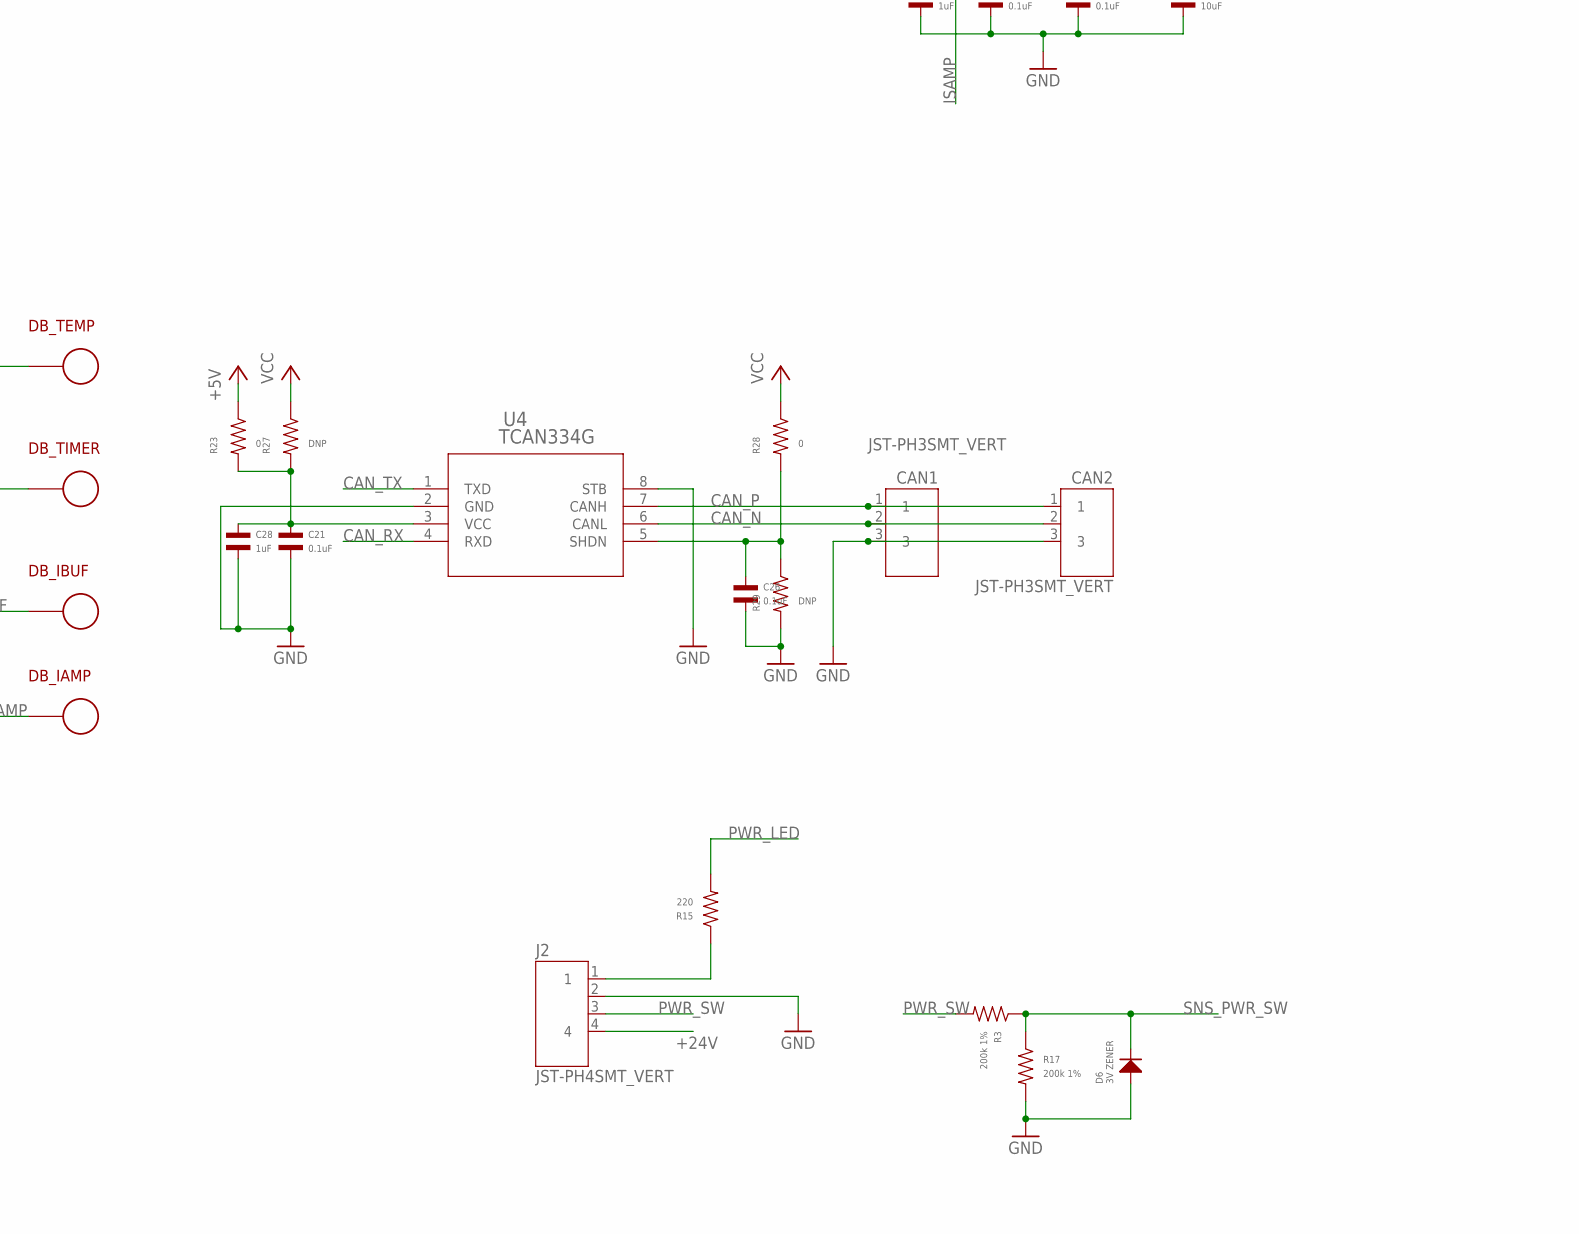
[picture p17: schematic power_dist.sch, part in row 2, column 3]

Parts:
C1, C22, C23: DNP; C0603
C2: 4.7uF 100V; C1206; MPN GRJ31CC72A475KE01K
C3, C7, C28: 1uF; C0603; MPN MF-CAP-0603-1uF
C4, C10: 10uF; C1206; MPN MF-CAP-1206-10uF
C5, C6, C8, C9, C11, C16, C17, C20, C21, C26: 0.1uF; C0603; MPN MF-CAP-0603-0.1uF
C12, C27: .1uF 100V; C0603; MPN GRM188R72A104KA35D
C13: 27nF 100uF; C0603; MPN C0603C273K1RAC7867
C14: 10nF; C0603; MPN MF-CAP-0603-0.01uF
C15: 1uF 100V; C0805; MPN GCM21BC72A105KE36L
C18, C19: 0.01uF; C0603; MPN MF-CAP-0603-0.01uF
C24: 1uF; C0402; MPN MF-CAP-0402-1uF
C25: 22uF; C1206; MPN CL31B226KPHNNNE
CAN1, CAN2: JST-PH3SMT_VERT; JST_B3B_PH-SM4-TB(LF)(SN); MPN B3B-PH-SM4-TB(LF)(SN)
D1, D2: MF-DIO-SOD123-1N4148; SOD-123
D3, D9: SMBJ51CA-E3/52214AB; DIODE_DO-214AB; MPN SMC5K51A-M3/I
D4, D5: LED_SINGLE-0603; LED0603; MPN MF-LED-0603-RED
D6: 3V ZENER; SOD-123; MPN MMSZ4682T1G
D8: FSV10150VTO277-3L_ONS-L; TO277-3L_ONS-L; MPN FSV10150V
DB_3, DB_5: PAD24AWG_PAD; 24AWG_PAD
DB_FLT: PAD24AWG_PAD; 24AWG_PAD
DB_G: PAD24AWG_PAD; 24AWG_PAD
DB_IAMP: PAD24AWG_PAD; 24AWG_PAD
DB_IB: PAD24AWG_PAD; 24AWG_PAD
DB_IBUF: PAD24AWG_PAD; 24AWG_PAD
DB_IS: PAD24AWG_PAD; 24AWG_PAD
DB_LEN: PAD24AWG_PAD; 24AWG_PAD
DB_TEMP: PAD24AWG_PAD; 24AWG_PAD
DB_TIMER: PAD24AWG_PAD; 24AWG_PAD
DB_VIN: PAD24AWG_PAD; 24AWG_PAD
DB_VSW: PAD24AWG_PAD; 24AWG_PAD
J1: JST-ZH6SMT_VERT; JST_B6B-ZR-SM4-TF(LF)(SN); MPN B6B-ZR-SM4-TF(LF)(SN)
J2: JST-PH4SMT_VERT; JST_B4B_PH-SM4-TB(LF)(SN); MPN B4B-PH-SM4-TB(LF)(SN)
J3: JST-PH5VERT; JST_B5B_PH-SM4-TB(LF)(SN); MPN B5B-PH-SM4-TB(LF)(SN)
L1: SRN4018-220M; IND_BOURNS_SRN4018; MANUFACTURER_PART_NUMBER 74404042470
L2: 74404024100; IND_4024100_WRE; MPN MF-RES-0805-0
P1, P2, P3, P4, P5, P6: XT30P; MPN XT30UPB-F
P7: XT90PW-M
Q1, Q2, Q3: PSMN4R8-100BSEJ; D2PAK_SOT404_NEX; MANUFACTURER_PART_NUMBER PSMN3R7-100BSE
Q4: N-CHANNEL_FET_SOT-23-3; SOT-23-3; MPN BSS123
Q5: P-CHANNEL_FET_SOT-23-3; SOT-23-3; MPN ZXMP10A13FTA
R1, R25: DNP; R0603
R2, R16, R22: 100k; R0603; MPN MF-RES-0603-100K
R3, R12, R14, R17: 200k 1%; R0603; MPN RC0603FR-07200KL
R4: 0.5mOhm; SHUNT2512; MPN WSLF2512L5000FEA
R5: 10; R0603; MPN MF-RES-0603-10
R6: 1k; R0603; MPN MF-RES-0603-1K
R7, R20: 47k 1%; R0603; MPN RC0603FR-0747KL
R8: 6.8k 1%; R0603; MPN RC0603FR-076K8L
R9, R10, R15: 220; R0603; MPN MF-RES-0603-220
R11, R13: 4.7M 1%; R0603; MPN RC0603FR-074M7L
R18: 140k 1%; R0603; MPN RC0603FR-07140KL
R19: 499k 1%; R0603; MPN RC0603FR-07499KL
R21: 33k; R0603; MPN RC0603FR-0733KL
R23, R24, R26, R28, R30: 0; R0603; MPN MF-RES-0603-0
R27, R29: DNP; R0603; MPN MF-RES-0603-0
SH1: SHORTMEDIUM; SHORT_TOP-MEDIUM
U1: MAX15062AATA+T; 21-0487A_MXM; MANUFACTURER_PART_NUMBER MAX15062BATA+T
U2: STM32G474CEU6; QFN50P700X700X60-49N; MPN STM32G474CEU6
U3: TPS2490DGSR; SOP50P490X110-10N; MPN TPS2490DGSR
U4: TCAN334G; SOIC8; MPN TCAN1057AEVDRQ1
U5: LT1787HVIMS8PBF; MSOP-8_MS; MPN LT1787HVIMS8
U6: STLM20DD9FUDFN-4L_STM-L; UDFN-4L_STM-L; MPN STLM20DD9F
U7: XC9265A331MR-G; SOT95P280X130-5N; MPN MF-REG-SOT235-3.3V-300mA
U$1, U$2, U$3, U$4: MOUNT; M2.5MOUNT

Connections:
3V3_EN: D1.CATHODE, D2.CATHODE, R2.P$2, U1.2 (EN/UVLO)
3V3_OVERRIDE: D1.ANODE, U2.26 (PB13)
+5V: C4.P$1, C24.P$1, DB_5.P$1, L1.1, R23.P$1, U1.4 (FB/VOUT), U7.1 (VIN), U7.3 (CE)
+24V: C2.P$1, C12.P$1, C27.P$1, D3.P$1 (1), D9.P$1 (1), DB_VIN.P$1, J2.4, P7.2, Q5.P$2 (SOURCE), R4.1, R11.P$2, R20.P$2, U1.1 (VIN)
CAN_N: CAN1.2, CAN2.2, U4.6 (CANL)
CAN_P: CAN1.1, CAN2.1, U4.7 (CANH)
CAN_RX: U2.33 (PA11), U4.4 (RXD)
CAN_TX: U2.34 (PA12), U4.1 (TXD)
FET_TEMP: DB_TEMP.P$1, U2.16 (PC4), U6.1 (VOUT)
FLT: DB_FLT.P$1, R21.P$1, U2.13 (PA5), U3.6 (PG)
GATE: Q1.1 (G), Q2.1 (G), Q3.1 (G), R5.P$2
GDRV: R5.P$1, R6.P$2, U3.8 (GATE)
GND: C1.P$2, C3.P$2, C4.P$2, C5.P$2, C6.P$2, C7.P$2, C8.P$2, C9.P$2, C10.P$2, C11.P$2, C12.P$2, C13.P$2, C14.P$2, C16.P$2, C18.P$2, C19.P$2, C20.P$2, C21.P$2, C23.P$2, C24.P$2, C25.P$2, C26.P$2, C28.P$2, CAN1.3, CAN2.3, D6.ANODE, DB_G.P$1, J1.4, J2.2, J3.5, Q4.P$2 (SOURCE), R1.P$2, R2.P$1, R8.P$1, R12.P$1, R14.P$1, R16.P$1, R17.P$2, R18.P$1, R29.P$2, R30.P$2, SH1.1, U1.7 (GND), U2.29 (PC6), U2.38 (PA15), U2.49 (THERMALPAD), U3.5 (GND), U4.2 (GND), U4.8 (STB), U5.4 (VEE), U6.3 (GND), U7.2 (GND)
GPIO1: J3.4, U2.39 (PC10)
GPIO2: J3.3, U2.40 (PC11)
GPIO3: J3.2, U2.41 (PB3)
ISAMP: C22.P$2, DB_IS.P$1, R25.P$2, U2.17 (PB0), U5.5 (VOUT)
ISAMP_AMP: DB_IAMP.P$1, U2.30 (PA8)
ISAMP_BIAS: C20.P$1, C22.P$1, DB_IB.P$1, R24.P$1, R25.P$1, R26.P$2, U2.12 (PA4)
ISAMP_BUF: DB_IBUF.P$1, U2.18 (PB1), U2.28 (PB15)
LED1: D4.CATHODE, U2.8 (PA0)
LED2: D5.CATHODE, U2.47 (PB9)
unnamed: R30.P$1, U1.5 (MODE)
unnamed: J2.1, R15.P$1
unnamed: R24.P$2, U5.6 (VBIAS)
unnamed: C3.P$1, U1.3 (VCC)
unnamed: C23.P$1, U2.11 (PA3)
unnamed: C17.P$1, U5.1 (FIL-)
unnamed: C17.P$2, U5.8 (FIL+)
unnamed: D4.ANODE, R9.P$1
unnamed: C13.P$1, R6.P$1
unnamed: R26.P$1, U2.9 (PA1)
unnamed: Q5.P$3 (DRAIN), R19.P$2
unnamed: R18.P$2, R19.P$1, U3.1 (EN)
unnamed: Q4.P$3 (DRAIN), R22.P$1
unnamed: D5.ANODE, R10.P$1
unnamed: C1.P$1, R1.P$1, U$3.P$1
unnamed: Q5.P$1 (GATE), R20.P$1, R22.P$2
unnamed: C21.P$1, C28.P$1, R23.P$2, R27.P$2, U4.3 (VCC)
unnamed: L2.2, U7.5 (LX)
unnamed: C26.P$1, R28.P$2, R29.P$1, U4.5 (SHDN)
NRST: C5.P$1, J1.2, U2.7 (PG10-NRST)
PGND: C2.P$2, C15.P$2, C27.P$2, D3.P$2 (2), D8.1 (ANODE), D8.2 (ANODE_2), D9.P$2 (2), P1.1, P2.1, P3.1, P4.1, P5.1, P6.1, P7.1, SH1.2
PROG: R7.P$1, R8.P$2, U3.3 (PROG)
PWR_LED: R15.P$2, U2.25 (PB12)
PWR_SW: D2.ANODE, J2.3, R3.P$2
SNS_PWR_SW: D6.CATHODE, R3.P$1, R17.P$1, U2.10 (PA2)
SWCLK: J1.5, U2.37 (PA14)
SWDIO: J1.3, U2.36 (PA13)
TIMER: C14.P$1, DB_TIMER.P$1, U2.24 (PB11), U3.4 (TIMER)
TPS_EN: DB_LEN.P$1, Q4.P$1 (GATE), R16.P$2, U2.3 (PC14-OSC32_IN)
VCC: C6.P$1, C7.P$1, C8.P$1, C9.P$1, C10.P$1, C11.P$1, C16.P$1, C25.P$1, DB_3.P$1, J1.6, J3.1, L2.1, R9.P$2, R10.P$2, R21.P$2, R27.P$1, R28.P$1, U2.1 (VBAT), U2.20 (VREF+), U2.21 (VDDA), U2.23 (VDD_1), U2.35 (VDD_2), U2.48 (VDD_3), U6.4 (VCC), U7.4 (VOUT)
VIN_SAMP: C18.P$1, R11.P$1, R12.P$2, U2.27 (PB14)
VREF: R7.P$2, U3.2 (VREF)
VSENSE: Q1.2 (D), Q2.2 (D), Q3.2 (D), R4.2
VSENSE_HIGH: R4.3 (S1), U3.10 (VCC), U5.7 (VS+)
VSENSE_LOW: R4.4 (S2), U3.9 (SENSE), U5.2 (VS-)
VSW: L1.2, U1.8 (LX)
VSWITCHED: C15.P$1, D8.3 (CATHODE), DB_VSW.P$1, P1.2, P2.2, P3.2, P4.2, P5.2, P6.2, Q1.3 (S), Q2.3 (S), Q3.3 (S), R13.P$2, U3.7 (OUT)
VSWITCHED_SAMP: C19.P$1, R13.P$1, R14.P$2, U2.15 (PA7)

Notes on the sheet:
mjbots power dist r4.5b (c) 2023 mjbots Robotic Systems Licensed under the Apache 2.0 License https://www.apache.org/licenses/LICENSE-2.0
PC13/PA15/PC6 Version 100
If this is revved, put a zener in parallel with R20 so that R20 can be equal to R22.

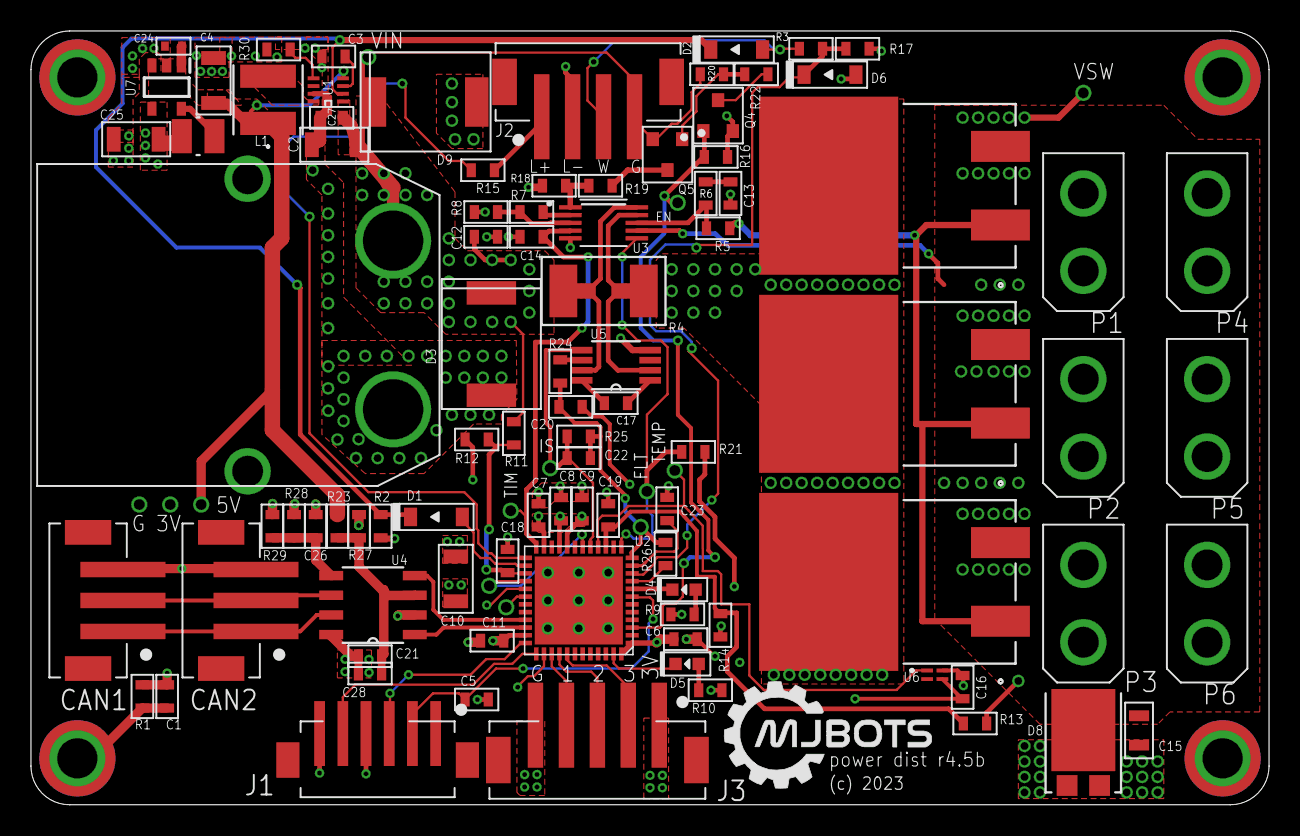
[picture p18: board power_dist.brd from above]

Board: 4 copper layers, 80.0 x 50.0 mm, 110 parts (0 on the bottom side), 60 nets.

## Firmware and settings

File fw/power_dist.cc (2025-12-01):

// Copyright 2023 mjbots Robotic Systems, LLC.  info@mjbots.com
//
// Licensed under the Apache License, Version 2.0 (the "License");
// you may not use this file except in compliance with the License.
// You may obtain a copy of the License at
//
//     http://www.apache.org/licenses/LICENSE-2.0
//
// Unless required by applicable law or agreed to in writing, software
// distributed under the License is distributed on an "AS IS" BASIS,
// WITHOUT WARRANTIES OR CONDITIONS OF ANY KIND, either express or implied.
// See the License for the specific language governing permissions and
// limitations under the License.

#include <numeric>

#include "mbed.h"

#include "mjlib/base/assert.h"
#include "mjlib/base/tokenizer.h"
#include "mjlib/base/limit.h"
#include "mjlib/micro/async_exclusive.h"
#include "mjlib/micro/async_stream.h"
#include "mjlib/micro/callback_table.h"
#include "mjlib/micro/command_manager.h"
#include "mjlib/micro/persistent_config.h"
#include "mjlib/micro/pool_ptr.h"
#include "mjlib/micro/telemetry_manager.h"
#include "mjlib/multiplex/micro_server.h"
#include "mjlib/multiplex/micro_stream_datagram.h"

#include "fw/fdcan.h"
#include "fw/fdcan_micro_server.h"
#include "fw/firmware_info.h"
#include "fw/git_info.h"
#include "fw/lm5066.h"
#include "fw/millisecond_timer.h"
#include "fw/power_dist_hw.h"
#include "fw/stm32g4_flash.h"
#include "fw/uuid.h"

namespace base = mjlib::base;
namespace micro = mjlib::micro;
namespace multiplex = mjlib::multiplex;
using Value = multiplex::MicroServer::Value;
using mjlib::base::Limit;
using FDCan = fw::FDCan;

namespace {

template <typename T>
void Store(T& out, T value) {
  std::memcpy(&out, &value, sizeof(value));
}

template <typename T>
Value IntMapping(T value, size_t type) {
  switch (type) {
    case 0: return static_cast<int8_t>(value);
    case 1: return static_cast<int16_t>(value);
    case 2: return static_cast<int32_t>(value);
    case 3: return static_cast<float>(value);
  }
  MJ_ASSERT(false);
  return static_cast<int8_t>(0);
}

template <typename T>
Value ScaleSaturate(float value, float scale) {
  if (!std::isfinite(value)) {
    return std::numeric_limits<T>::min();
  }

  const float scaled = value / scale;
  const auto max = std::numeric_limits<T>::max();
  // We purposefully limit to +- max, rather than to min.  The minimum
  // value for our two's complement types is reserved for NaN.
  return Limit<T>(static_cast<T>(scaled), -max, max);
}

Value ScaleMapping(float value,
                   float int8_scale, float int16_scale, float int32_scale,
                   size_t type) {
  switch (type) {
    case 0: return ScaleSaturate<int8_t>(value, int8_scale);
    case 1: return ScaleSaturate<int16_t>(value, int16_scale);
    case 2: return ScaleSaturate<int32_t>(value, int32_scale);
    case 3: return Value(value);
  }
  MJ_ASSERT(false);
  return Value(static_cast<int8_t>(0));
}

Value ScaleTemperature(float value, size_t type) {
  return ScaleMapping(value, 1.0f, 0.1f, 0.001f, type);
}

Value ScaleCurrent(float value, size_t type) {
  // For now, current and temperature have identical scaling.
  return ScaleTemperature(value, type);
}

Value ScaleVoltage(float value, size_t type) {
  return ScaleMapping(value, 0.5f, 0.1f, 0.001f, type);
}

int16_t ReadInt16Mapping(Value value) {
  return std::visit([](auto a) {
      return static_cast<int16_t>(a);
    }, value);
}

int32_t ReadInt32Mapping(Value value) {
  return std::visit([](auto a) {
    return static_cast<int32_t>(a);
  }, value);
}

struct ValueScaler {
  float int8_scale;
  float int16_scale;
  float int32_scale;

  float operator()(int8_t value) const {
    if (value == std::numeric_limits<int8_t>::min()) {
      return std::numeric_limits<float>::quiet_NaN();
    }
    return value * int8_scale;
  }

  float operator()(int16_t value) const {
    if (value == std::numeric_limits<int16_t>::min()) {
      return std::numeric_limits<float>::quiet_NaN();
    }
    return value * int16_scale;
  }

  float operator()(int32_t value) const {
    if (value == std::numeric_limits<int32_t>::min()) {
      return std::numeric_limits<float>::quiet_NaN();
    }
    return value * int32_scale;
  }

  float operator()(float value) const {
    return value;
  }
};

enum class Register {
  kState = 0x000,
  kFaultCode = 0x001,
  kSwitchStatus = 0x002,
  kLockTime = 0x003,
  kBootTime = 0x004,
  kOutputVoltage = 0x010,
  kOutputCurrent = 0x011,
  kTemperature = 0x012,
  kEnergy = 0x013,

  kUuid1 = 0x150,
  kUuid2 = 0x151,
  kUuid3 = 0x152,
  kUuid4 = 0x153,

  kUuidMask1 = 0x154,
  kUuidMask2 = 0x155,
  kUuidMask3 = 0x156,
  kUuidMask4 = 0x157,

  kUuidMaskCapable = 0x158,
};

enum State {
  kPowerOff,
  kPrecharging,
  kPowerOn,
  kFault,

  kNumStates,
};
}

namespace mjlib {
namespace base {

template <>
struct IsEnum<State> {
  static constexpr bool value = true;

  using S = State;
  static std::array<std::pair<S, const char*>, S::kNumStates> map() {
    return { {
        { S::kPowerOff, "power_off" },
        { S::kPrecharging, "precharging" },
        { S::kPowerOn, "power_on" },
        { S::kFault, "fault" },
      }};
  }
};

}
}

namespace {

void SetClock2() {
  RCC_ClkInitTypeDef RCC_ClkInitStruct;

  RCC_ClkInitStruct.ClockType = (
      RCC_CLOCKTYPE_SYSCLK | RCC_CLOCKTYPE_HCLK | RCC_CLOCKTYPE_PCLK1 |
      RCC_CLOCKTYPE_PCLK2);
  RCC_ClkInitStruct.SYSCLKSource = RCC_SYSCLKSOURCE_PLLCLK;
  RCC_ClkInitStruct.AHBCLKDivider = RCC_SYSCLK_DIV1; // 170 MHz
  RCC_ClkInitStruct.APB1CLKDivider = RCC_HCLK_DIV2;  // 85 MHz
  RCC_ClkInitStruct.APB2CLKDivider = RCC_HCLK_DIV2;  // 85 MHz

  if (HAL_RCC_ClockConfig(&RCC_ClkInitStruct, FLASH_LATENCY_6) != HAL_OK) {
    return;
  }

  {
    RCC_PeriphCLKInitTypeDef PeriphClkInit = {};

    PeriphClkInit.PeriphClockSelection =
        RCC_PERIPHCLK_FDCAN |
        RCC_PERIPHCLK_ADC12 |
        RCC_PERIPHCLK_ADC345;
    PeriphClkInit.FdcanClockSelection = RCC_FDCANCLKSOURCE_PCLK1;
    PeriphClkInit.Adc12ClockSelection = RCC_ADC12CLKSOURCE_SYSCLK;
    PeriphClkInit.Adc345ClockSelection = RCC_ADC345CLKSOURCE_SYSCLK;
    if (HAL_RCCEx_PeriphCLKConfig(&PeriphClkInit) != HAL_OK)
    {
      mbed_die();
    }
  }

  SystemCoreClockUpdate();
}

class OpAmpInvertingAmplifier {
 public:
  OpAmpInvertingAmplifier(OPAMP_TypeDef* opamp) {
    ctx_.Instance = opamp;
    ctx_.Init.PowerMode = OPAMP_POWERMODE_NORMAL;
    ctx_.Init.Mode = OPAMP_PGA_MODE;
    ctx_.Init.InvertingInput = OPAMP_INVERTINGINPUT_IO0;  // N/A in OPAMP_PGA_MODE
    ctx_.Init.NonInvertingInput = OPAMP_NONINVERTINGINPUT_DAC;
    ctx_.Init.InternalOutput = DISABLE;
    ctx_.Init.TimerControlledMuxmode = OPAMP_TIMERCONTROLLEDMUXMODE_DISABLE;
    ctx_.Init.InvertingInputSecondary = {};
    ctx_.Init.NonInvertingInputSecondary = {};
    ctx_.Init.PgaConnect = OPAMP_PGA_CONNECT_INVERTINGINPUT_IO0_BIAS;
    ctx_.Init.PgaGain = OPAMP_PGA_GAIN_8_OR_MINUS_7;
    ctx_.Init.UserTrimming = OPAMP_TRIMMING_FACTORY;
    ctx_.Init.TrimmingValueP = {};
    ctx_.Init.TrimmingValueN = {};

    if (HAL_OPAMP_Init(&ctx_) != HAL_OK) {
      mbed_die();
    }

    HAL_OPAMP_Start(&ctx_);
  }

  ~OpAmpInvertingAmplifier() {
    HAL_OPAMP_Stop(&ctx_);
  }

  OPAMP_HandleTypeDef ctx_ = {};
};

class OpAmpBuffer {
 public:
  enum Output {
    kInternal,
    kExternal,
  };

  OpAmpBuffer(OPAMP_TypeDef* opamp, int input_channel, Output output = kInternal) {
    ctx_.Instance = opamp;
    ctx_.Init.PowerMode = OPAMP_POWERMODE_NORMAL;
    ctx_.Init.Mode = OPAMP_FOLLOWER_MODE;
    ctx_.Init.InvertingInput = {};  // N/A for follower
    ctx_.Init.NonInvertingInput = MapInput(input_channel);
    ctx_.Init.InternalOutput = (output == kInternal) ? ENABLE : DISABLE;
    ctx_.Init.TimerControlledMuxmode = OPAMP_TIMERCONTROLLEDMUXMODE_DISABLE;
    ctx_.Init.InvertingInputSecondary = {};
    ctx_.Init.NonInvertingInputSecondary = {};
    ctx_.Init.PgaConnect = {};
    ctx_.Init.PgaGain = {};
    ctx_.Init.UserTrimming = OPAMP_TRIMMING_FACTORY;
    ctx_.Init.TrimmingValueP = {};
    ctx_.Init.TrimmingValueN = {};

    if (HAL_OPAMP_Init(&ctx_) != HAL_OK) {
      mbed_die();
    }

    HAL_OPAMP_Start(&ctx_);
  }

  ~OpAmpBuffer() {
    HAL_OPAMP_Stop(&ctx_);
  }

  static int MapInput(int input_channel) {
    switch (input_channel) {
      case 0: return OPAMP_NONINVERTINGINPUT_IO0;
      case 1: return OPAMP_NONINVERTINGINPUT_IO1;
      case 2: return OPAMP_NONINVERTINGINPUT_IO2;
      case 3: return OPAMP_NONINVERTINGINPUT_IO3;
    }
    return 0;
  }

  OPAMP_HandleTypeDef ctx_ = {};
};

void ConfigureDAC1(fw::MillisecondTimer* timer) {
  __HAL_RCC_DAC1_CLK_ENABLE();

  // Initialize our gpio:
  {
    GPIO_InitTypeDef init = {};
    init.Pin = GPIO_PIN_4;
    init.Mode = GPIO_MODE_ANALOG;
    init.Pull = {};
    init.Speed = {};
    init.Alternate = {};
    HAL_GPIO_Init(GPIOA, &init);
  }

  // ISAMP_BIAS is PA4 -> DAC1_OUT1
  DAC1->MCR = (
      (0 << DAC_MCR_HFSEL_Pos) | // High frequency mode disabled
      (0 << DAC_MCR_MODE1_Pos) | // external pin with buffer enabled
      0);

  DAC1->CR = (
      (DAC_CR_EN1) | // enable channel 1
      0);

  // tWAKEUP is defined as max 7.5us
  timer->wait_us(10);

  // Write a half voltage.
  DAC1->DHR12R1 = 2048;
}

void ConfigureDAC4(fw::MillisecondTimer* timer) {
  __HAL_RCC_DAC4_CLK_ENABLE();

  DAC4->MCR = (
      (0 << DAC_MCR_HFSEL_Pos) | // High frequency mode disabled
      (3 << DAC_MCR_MODE1_Pos) | // internal with no buffer
      (3 << DAC_MCR_MODE2_Pos) | // internal with no buffer
      0);

  DAC4->CR = (
      (DAC_CR_EN1) | // enable channel 1
      (DAC_CR_EN2) | // enable channel 2
      0);

  // tWAKEUP is defined as max 7.5us
  timer->wait_us(10);

  // Write a half voltage to channel 1 and 2.
  DAC4->DHR12R1 = 2048;
  DAC4->DHR12R2 = 2048;
}

void ConfigureDAC3(fw::MillisecondTimer* timer) {
  __HAL_RCC_DAC3_CLK_ENABLE();

  DAC3->MCR = (
      (0 << DAC_MCR_HFSEL_Pos) | // High frequency mode disabled
      (3 << DAC_MCR_MODE1_Pos) | // internal with no buffer
      (3 << DAC_MCR_MODE2_Pos) | // internal with no buffer
      0);

  DAC3->CR = (
      (DAC_CR_EN1) | // enable channel 1
      (DAC_CR_EN2) | // enable channel 2
      0);

  // tWAKEUP is defined as max 7.5us
  timer->wait_us(10);

  // Write a half voltage to channel 1 and 2.
  DAC3->DHR12R1 = 2048;
  DAC3->DHR12R2 = 2048;
}

void ConfigureADC(ADC_TypeDef* adc, int channel_sqr, fw::MillisecondTimer* timer) {
  // Disable it to ensure we are in a known state.
  if (adc->CR & ADC_CR_ADEN) {
    adc->CR |= ADC_CR_ADDIS;
    while (adc->CR & ADC_CR_ADEN);
  }

  // The prescaler must be at least 6x to be able to accurately read
  // across all channels.  If it is too low, you'll see errors that
  // look like quantization, but not in a particularly uniform way
  // and not consistently across each of the channels.
  auto map_adc_prescale = [](int prescale) {
    if (prescale == 1) { return 0; }
    if (prescale == 2) { return 1; }
    if (prescale == 4) { return 2; }
    if (prescale == 6) { return 3; }
    if (prescale == 8) { return 4; }
    if (prescale == 10) { return 5; }
    if (prescale == 12) { return 6; }
    if (prescale == 16) { return 7; }
    if (prescale == 32) { return 8; }
    if (prescale == 64) { return 9; }
    if (prescale == 128) { return 10; }
    if (prescale == 256) { return 11; }
    MJ_ASSERT(false);
    return 0;
  };

  constexpr int kAdcPrescale = 8;

  ADC12_COMMON->CCR =
      (map_adc_prescale(kAdcPrescale) << ADC_CCR_PRESC_Pos);
  ADC345_COMMON->CCR =
      (map_adc_prescale(kAdcPrescale) << ADC_CCR_PRESC_Pos);

  adc->CR &= ~ADC_CR_DEEPPWD;
  adc->CR |= ADC_CR_ADVREGEN;
  timer->wait_us(20);
  adc->CR |= ADC_CR_ADCAL;
  while (adc->CR & ADC_CR_ADCAL);
  timer->wait_us(1);

  adc->ISR |= ADC_ISR_ADRDY;
  adc->CR |= ADC_CR_ADEN;
  while (!(adc->ISR & ADC_ISR_ADRDY));

  adc->ISR |= ADC_ISR_ADRDY;
  adc->CFGR &= ~(ADC_CFGR_CONT);
  adc->CFGR2 = (
      (0 << ADC_CFGR2_SMPTRIG_Pos) |
      (0 << ADC_CFGR2_BULB_Pos) |
      (0 << ADC_CFGR2_SWTRIG_Pos) |
      (0 << ADC_CFGR2_GCOMP_Pos) |
      (0 << ADC_CFGR2_ROVSM_Pos) |
      (0 << ADC_CFGR2_TROVS_Pos) |
      (0 << ADC_CFGR2_JOVSE_Pos) |
      (5 << ADC_CFGR2_OVSS_Pos) |  // 5 bit shift right
      (4 << ADC_CFGR2_OVSR_Pos) |  // oversample 32x
      (1 << ADC_CFGR2_ROVSE_Pos) | // enable regular oversampling
      0);


  adc->SQR1 =
      (0 << ADC_SQR1_L_Pos) | // length 1
      (channel_sqr << ADC_SQR1_SQ1_Pos);
  auto make_cycles = [](auto v) {
                       return
                           (v << 0) |
                           (v << 3) |
                           (v << 6) |
                           (v << 9) |
                           (v << 12) |
                           (v << 15) |
                           (v << 18) |
                           (v << 21) |
                           (v << 24);
                     };
  adc->SMPR1 = make_cycles(2);  // 47 ADC cycles
  adc->SMPR2 = make_cycles(2);
}

struct CanConfig {
  uint32_t prefix = 0;

  template <typename Archive>
  void Serialize(Archive* a) {
    a->Visit(MJ_NVP(prefix));
  }

  bool operator==(const CanConfig& rhs) const {
    return prefix == rhs.prefix;
  }
};

const int kShutdownTimeoutMs = 5000;
const int kMinOffTimeMs = 500;

class PowerDist : public mjlib::multiplex::MicroServer::Server {
 public:
  struct Config {
    float current_sense_ohm = 0.0005f;
    bool disable_sleep = false;

    template <typename Archive>
    void Serialize(Archive* a) {
      a->Visit(MJ_NVP(current_sense_ohm));
      a->Visit(MJ_NVP(disable_sleep));
    }
  };

  struct Status {
    State state = kPowerOff;
    int8_t fault_code = 0;
    int8_t tps2490_fault = 0;
    int8_t switch_status = 0;
    int16_t lock_time_100ms = 0;

    float input_voltage_V = 0.0f;
    float output_voltage_V = 0.0f;
    float output_current_A = 0.0f;
    float fet_temp_C = 0.0f;
    int32_t energy_uW_hr = 0;

    int16_t int_temp_raw = 0;
    float int_temp_C = 0.0f;


    int32_t precharge_timeout_ms = 0;
    int32_t shutdown_timeout_ms = 0;

    int32_t off_time_ms = 0;

    uint16_t isamp_offset = 0;
    uint16_t isamp_average = 0;

    int8_t force_output = 0;

    template <typename Archive>
    void Serialize(Archive* a) {
      a->Visit(MJ_NVP(state));
      a->Visit(MJ_NVP(fault_code));
      a->Visit(MJ_NVP(tps2490_fault));
      a->Visit(MJ_NVP(switch_status));
      a->Visit(MJ_NVP(lock_time_100ms));

      a->Visit(MJ_NVP(input_voltage_V));
      a->Visit(MJ_NVP(output_voltage_V));
      a->Visit(MJ_NVP(output_current_A));
      a->Visit(MJ_NVP(fet_temp_C));
      a->Visit(MJ_NVP(energy_uW_hr));

      a->Visit(MJ_NVP(int_temp_raw));
      a->Visit(MJ_NVP(int_temp_C));

      a->Visit(MJ_NVP(precharge_timeout_ms));
      a->Visit(MJ_NVP(shutdown_timeout_ms));

      a->Visit(MJ_NVP(off_time_ms));

      a->Visit(MJ_NVP(isamp_offset));
      a->Visit(MJ_NVP(isamp_average));

      a->Visit(MJ_NVP(force_output));
    }
  };

  PowerDist() :
      gpio1_(GPIO1, 1),
      gpio2_(GPIO2, 0),
      can_shdn_(CAN_SHDN, 0),
      can_([&]() {
             fw::FDCan::Options options;
             options.td = CAN_TX;
             options.rd = CAN_RX;
             options.slow_bitrate = 1000000;
             options.fast_bitrate = 5000000;

             options.fdcan_frame = true;
             options.bitrate_switch = true;
             options.automatic_retransmission = true;

             options.delay_compensation = true;

             options.tdc_offset = 13;
             options.tdc_filter = 2;

             return options;
           }()),
      fdcan_micro_server_(&can_),
      multiplex_protocol_(&pool_, &fdcan_micro_server_, {}) {
    multiplex_protocol_.config()->id = 32;
  }

  void MaybeUpdateFilters() {
    // We only update our config if it has actually changed.
    // Re-initializing the CAN-FD controller can cause packets to
    // be lost, so don't do it unless actually necessary.
    if (can_config_ == old_can_config_ &&
        multiplex_protocol_.config()->id == old_multiplex_id_) {
      return;
    }

    old_can_config_ = can_config_;
    old_multiplex_id_ = multiplex_protocol_.config()->id;

    FDCan::Filter filters[4] = {};
    filters[0].id1 = (can_config_.prefix << 16) | old_multiplex_id_;
    filters[0].id2 = 0x1fff00ffu;
    filters[0].mode = FDCan::FilterMode::kMask;
    filters[0].action = FDCan::FilterAction::kAccept;
    filters[0].type = FDCan::FilterType::kExtended;

    filters[1].id1 = (can_config_.prefix << 16) | 0x7f;
    filters[1].id2 = 0x1fff00ffu;
    filters[1].mode = FDCan::FilterMode::kMask;
    filters[1].action = FDCan::FilterAction::kAccept;
    filters[1].type = FDCan::FilterType::kExtended;

    filters[2].id1 = (can_config_.prefix << 16) | old_multiplex_id_;
    filters[2].id2 = 0x1fff00ffu;
    filters[2].mode = FDCan::FilterMode::kMask;
    filters[2].action = FDCan::FilterAction::kAccept;
    filters[2].type = FDCan::FilterType::kStandard;

    filters[3].id1 = (can_config_.prefix << 16) | 0x7f;
    filters[3].id2 = 0x1fff00ffu;
    filters[3].mode = FDCan::FilterMode::kMask;
    filters[3].action = FDCan::FilterAction::kAccept;
    filters[3].type = FDCan::FilterType::kStandard;

    FDCan::FilterConfig filter_config;
    filter_config.begin = std::begin(filters);
    filter_config.end = std::end(filters);
    filter_config.global_std_action = FDCan::FilterAction::kReject;
    filter_config.global_ext_action = FDCan::FilterAction::kReject;
    can_.ConfigureFilters(filter_config);

    fdcan_micro_server_.SetPrefix(can_config_.prefix);
  }

  /// multiplex::MicroServer

  void StartFrame() override {
    discard_all_ = false;
  }

  Action CompleteFrame() override {
    if (discard_all_) {
      return kDiscard;
    }
    return kAccept;
  }

  WriteAction Write(multiplex::MicroServer::Register reg,
                    const Value& value) override __attribute__((optimize("O3"))) {
    if (discard_all_) { return kDiscardRemaining; }

    switch (static_cast<Register>(reg)) {
      case Register::kState: {
        // TODO: For now, mark as not writeable.
        return kNotWriteable;
      }
      case Register::kLockTime: {
        status_.lock_time_100ms = ReadInt16Mapping(value);
        return kSuccess;
      }
      case Register::kFaultCode:
      case Register::kSwitchStatus:
      case Register::kBootTime:
      case Register::kOutputVoltage:
      case Register::kOutputCurrent:
      case Register::kTemperature:
      case Register::kEnergy:
      case Register::kUuid1:
      case Register::kUuid2:
      case Register::kUuid3:
      case Register::kUuid4:
      case Register::kUuidMaskCapable: {
        // Not writeable.
        return kNotWriteable;
      }

      case Register::kUuidMask1:
      case Register::kUuidMask2:
      case Register::kUuidMask3:
      case Register::kUuidMask4: {
        const auto uuid = uuid_.uuid();
        const auto index =
            (static_cast<int>(reg) -
             static_cast<int>(Register::kUuidMask1)) * 4;

        const auto expected = *(reinterpret_cast<const int32_t*>(&uuid[index]));
        const auto written = ReadInt32Mapping(value);
        if (expected != written) {
          discard_all_ = true;
          return kDiscardRemaining;
        }
        return kSuccess;
      }

    }

    // This is an unknown register.
    return kUnknownRegister;
  }

  multiplex::MicroServer::ReadResult Read(
      multiplex::MicroServer::Register reg,
      size_t type) const override {
    if (discard_all_) {
      return static_cast<uint32_t>(1);
    }
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
int main(void) {
  rcc_csr = RCC->CSR;

#if POWER_DIST_HW_REV >= 2
  SetClock2();
#else
#error "Unsupported target"
#endif

  // We use ADC5 for VSAMP_OUT
  __HAL_RCC_ADC12_CLK_ENABLE();
  __HAL_RCC_ADC345_CLK_ENABLE();

  fw::MillisecondTimer timer;

  DigitalIn hwrev0(HWREV_PIN0, PullUp);
  DigitalIn hwrev1(HWREV_PIN1, PullUp);
  DigitalIn hwrev2(HWREV_PIN2, PullUp);

  timer.wait_ms(2);

  const uint8_t this_hw_pins =
      0x07 & (~(hwrev0.read() |
                (hwrev1.read() << 1) |
                (hwrev2.read() << 2)));
  const uint8_t measured_hw_rev = [&]() {
    int i = 0;
    for (auto rev_pins : kHardwareInterlock) {
      if (rev_pins == this_hw_pins) { return i; }
      i++;
    }
    return -1;
  }();

  fw::g_measured_hw_rev = measured_hw_rev;

  // Check if the detected board revision level is in our compatible
  // set.
  const bool compatible = [&]() {
    for (auto possible_version : kCompatibleHwRev) {
      if (measured_hw_rev == possible_version) { return true; }
    }
    return false;
  }();
  MJ_ASSERT(compatible);



#if POWER_DIST_HW_REV >= 2
  RunRev2();
#else
#error "Unsupported target"
#endif
}

extern "C" {
  void abort() {
    mbed_die();
  }
}

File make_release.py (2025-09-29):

#!/usr/bin/python3

# Copyright 2025 mjbots Robotic Systems, LLC.  info@mjbots.com
#
# Licensed under the Apache License, Version 2.0 (the "License");
# you may not use this file except in compliance with the License.
# You may obtain a copy of the License at
#
#     http://www.apache.org/licenses/LICENSE-2.0
#
# Unless required by applicable law or agreed to in writing, software
# distributed under the License is distributed on an "AS IS" BASIS,
# WITHOUT WARRANTIES OR CONDITIONS OF ANY KIND, either express or implied.
# See the License for the specific language governing permissions and
# limitations under the License.

import datetime
import os
import subprocess
import sys
import argparse


def run(cmd):
    print('>{}'.format(cmd))
    subprocess.check_call(cmd, shell=True)

def main():
    parser = argparse.ArgumentParser(
        description=f'{__file__} is used to build the firmware and create a flashable .elf artifact.')
    parser.add_argument('outdir', nargs='?', default='release', help='Target directory for the build artifacts.')
    args = parser.parse_args()

    outdir = args.outdir
    os.makedirs(outdir, exist_ok=True)

    # Make sure git is clean first.
    dirty = (subprocess.run("git diff-index --quiet HEAD --",
                            shell=True).returncode != 0)
    if dirty:
        raise RuntimeError("git is dirty, cannot release!")
    git_hash = subprocess.check_output(
        "git rev-parse HEAD", shell=True).decode('utf8').strip()

    datestr = datetime.datetime.now().strftime('%Y%m%d')

    print("Details:")
    print(" Date:", datestr)
    print(" Output Directory:", outdir)
    print(" Git Hash:", git_hash)
    print("Building...")
    print()

    run('tools/bazel clean --expunge')
    run('tools/bazel build -c opt //...')

    run(f'cp bazel-bin/fw/power_dist.elf {outdir}/{datestr}-power_dist-{git_hash}.elf')

    print()
    print('DONE')

if __name__ == '__main__':
    main()

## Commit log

2020-12-02 Hardware designs
    [LM5066I_Design_Calculator_REV_C.XLSX, power_dist.brd, power_dist.sch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]
2020-12-07 Work towards functioning r4
    * Beginnings of firmware
    * Initial README and CHANGES
    * Start on r4.1 w/ fixed D3 footprint
    [power_dist.brd]
2020-12-09 Fix inconsistency in schematic
    [power_dist.sch]
2020-12-10 Initial stub of LM5066 support
    This seems to be able to read and report data, and at least input
    voltage seems reasonable.
    tview does seem to become corrupted frequently, possibly related to
    the CAN status spamming.
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2020-12-13 Draft r4.1 based on the LTC4380
    [power_dist.brd, power_dist.sch]
2020-12-13 Connect GND/PGND and fix XT90 TH size
    [power_dist.brd, power_dist.sch]
2020-12-13 Resize and draft place all silks
    [power_dist.brd, power_dist.sch]
2020-12-14 Rename all resistors, capacitors, and diodes
    [power_dist.brd, power_dist.sch]
2020-12-14 Fine place silks
    [power_dist.brd, power_dist.sch]
2020-12-14 Fix a few minor glitches
    [power_dist.brd, power_dist.sch]
2020-12-14 Fix more minor layout and naming glitches
    [power_dist.brd, power_dist.sch]
2020-12-14 Add more debugging pads
    [power_dist.brd, power_dist.sch]
2020-12-14 More debug pad position tweaks
    [power_dist.brd]
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2020-12-23 Capture remaining r4.1 artifacts
    [power_dist.brd, power_dist.sch]
2020-12-23 Rough placement of r4.2 with the TPS2490
    [LM5066I_Design_Calculator_REV_C.XLSX, TPS249x_8x_Design_Calculator_REV_B.xlsx, power_dist.brd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]
2020-12-23 r4.2 everything rough routed
    [power_dist.brd, power_dist.sch]
2020-12-23 Connect TIMER to an ADC and add a FET temperature sensor
    [power_dist.brd, power_dist.sch]
2020-12-23 Renumber all resistors and caps
    [power_dist.brd, power_dist.sch]
2020-12-23 Place all silks and add a few more debug points
    [power_dist.brd, power_dist.sch]
2021-01-05 Update version pins for r4.2
    [power_dist.brd, power_dist.sch]
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2021-01-06 WIP: Attempt unsuccessfully to get current sensing working on r4.1
    This moves the input to PB0 to be buffered by OPAMP3 before being
    amplified by OPAMP6. The amplification appears to be not working, and
    I'm not 100% sure the buffering is working either.
    [power_dist.cc]
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2021-01-08 Incorporate r4.1 feedback
    [power_dist.brd, power_dist.sch]
2021-01-08 Tweak silks and layouts, set isolate for all power nets
    [power_dist.brd, power_dist.sch]
2021-01-08 Fine silk placement
    [power_dist.brd]
2021-01-08 Slight silk tweak
    [power_dist.brd]
2021-01-10 Capture r4.2 as sent for mf
    [power_dist.brd, power_dist.sch]
2021-01-10 Update the solder mask to be more amenable to oshstencil
    [power_dist.brd, power_dist.sch]
2021-01-17 Fix a part number
    [power_dist.brd, power_dist.sch]
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2021-01-20 Start on r4.3
    This version dispenses with all the latching junk for main power, just
    leaving it for the 3.3V rail. Now, the stm32 is completely
    responsible for turning the main power on and off, which could allow
    it to reset the hot swap controller if need be.
    [power_dist.brd, power_dist.sch]
2021-01-20 Switch the LTC1787 filter to a 0.1uF
    [power_dist.brd, power_dist.sch]
2021-01-22 Updates for r4.3
    [power_dist.brd, power_dist.sch]
2021-01-22 Move some wires further apart
    Reduce the paste fill ratio under the stm32
    [power_dist.brd, power_dist.sch]
2021-01-22 Minor position tweaks after gerber viewing
    [power_dist.brd]
2021-01-24 Capture r4.3
    [power_dist.brd, power_dist.sch]
2021-02-13 Add part numbers, rev to 4.3b
    [power_dist.brd, power_dist.sch]
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2021-03-02 Capture r4.3b
    [power_dist.brd, power_dist.sch]
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2021-04-07 Include mechanical drawings and models for 4.3b
    [20210407-power_dist-r43b-mechanical.step]
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2022-11-04 Rev to use a staged 5V, then 3.3V regulator
    This way we have a 300mA 5V supply on board to use with a beefier CAN
    transceiver
    [TPS249x_8x_Design_Calculator_REV_B.xlsx, power_dist.brd, power_dist.sch]
2022-11-04 Switch to a 5V CAN transceiver
    Add enough 0 ohms and DNPs to support populating with a 3.3V native
    transceiver as well.
    [power_dist.brd, power_dist.sch]
2022-11-04 Minor improvements
    * Add a 5V debug pad
    * Tweak routing and silks
    [power_dist.brd, power_dist.sch]
2022-11-07 Tweak some silks
    [power_dist.brd]
2022-11-07 Switch the 27nF cap to one that exists
    [power_dist.brd, power_dist.sch]
2022-11-23 Fix TVS diode footprint
    [power_dist.brd, power_dist.sch]
2022-12-22 Update board version to r4.5
    [power_dist.brd, power_dist.sch]
2022-12-22 Reroute the regulators and lots of power things
    Try to improve the grounding and decoupling for the buck converters.
    Add some more decoupling caps and place them so as to hopefully reduce
    the amount of ground bounce noise that was interfering with current
    sensing.
    [power_dist.brd, power_dist.sch]
2022-12-22 Add a lot more vias
    [power_dist.brd]
2022-12-23 More tweaks
    [power_dist.brd, power_dist.sch]
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2022-12-23 Capture r4.4
    [power_dist.brd, power_dist.sch]
2022-12-23 More layout and silk tweaks
    [power_dist.brd]
2022-12-23 Switch PGND to the regulators to be a fill instead of trace
    [power_dist.brd]
2022-12-23 r4.5 as sent to mfg
    [power_dist.brd, power_dist.sch]
2022-12-28 Switch the XT90 drills from 3.7 to 3.9mm
    [power_dist.brd, power_dist.sch]
2022-12-31 Final version sent for mf
    [power_dist.brd, power_dist.sch]
2023-01-24 Bump version to 4.5b
    Scoot the input regulators around to give the 5V inductor more room
    [power_dist.brd, power_dist.sch]
2023-01-24 Improve noise in the power subsystem
    * Replace the 3.3V regulator with a linear one
    * The inductor is just swapped for a shunt, so that the switcher
    could be put back in for testing
    * Increase the 5V regulator input capacitance to 4.7uF from 1uF
    * Shift a bunch of stuff around to make room for the bigger cap
    [power_dist.brd, power_dist.sch]
2023-01-24 Connect the grounds on both sides of the 3V regulator
    [power_dist.brd]
2023-05-18 * Make the current sense resistor configurable * Provide a diagnostic channel means of forcing the output on/off
2023-05-18 Capture r4.5b
    [power_dist.brd, power_dist.sch]
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2024-05-22 Create two examples showing how to access the power_dist data with python
2024-07-10 Remove legacy board files
    [power_dist.brd, power_dist.sch, power_dist_r3_1.step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]
2024-07-10 Move all the power_dist board files into their own subdirectory
    [20210407-power_dist-r43b-mechanical.step, LM5066I_Design_Calculator_REV_C.XLSX, power_dist.brd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]
2024-09-05 mjpower-ss
    New board, largely same functionality as power_dist.
    + onboard switch
    + smaller size (50x70mm vs 50x80mm)
    + design files in KiCAD
    - CAN-FD monitoring and soft-switch lockout
    Still has:
    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
    [20240827-mjpower-ss-r2.step, Amass_XT30UPB-F.step, B4B-PH-SM4-TB.step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]
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2025-12-01 Fix CAN-FD communication
    Follow up to 8a68840a64530206a1917cc91bbe746aeba026e8
    1. We accidentally turned off delay compensation, which is necessary
    to actually transmit.
    2. Automatic retransmission should be enabled, to match other
    peripheral devices like moteus.
    [power_dist.cc]

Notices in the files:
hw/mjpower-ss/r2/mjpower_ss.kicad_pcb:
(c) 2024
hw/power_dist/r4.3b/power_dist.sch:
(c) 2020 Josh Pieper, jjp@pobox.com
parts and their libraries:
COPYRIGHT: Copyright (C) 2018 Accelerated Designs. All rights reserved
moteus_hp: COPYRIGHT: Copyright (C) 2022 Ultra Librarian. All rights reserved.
